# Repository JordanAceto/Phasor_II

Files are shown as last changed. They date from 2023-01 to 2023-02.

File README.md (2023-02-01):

# Phasor II Guitar Pedal

## 6-stage optical phase shifter pedal ala the Mu-tron II with extra features

- Fits in a Hammond BB style box
- Classic `RATE`, `DEPTH`, and `FEEDBACK` controls
- Powered by a standard guitar pedal style center-negative 9VDC power supply
- Expression pedal/CV input jack
    - Connect a Moog EP-3 or similar expression pedal with a TRS cable
    - Or inject a Control Voltage in the range [0v, +5v] with a TS cable
    - An internal jumper selects the destination for the modulation
        - `LFO DEPTH`
        - `LFO RATE`
        - `MANUAL SWEEP`

## [SCHEMATIC](https://github.com/JordanAceto/Phasor_II/blob/main/main_pcb/docs/phasor_II-schematic.pdf)

---

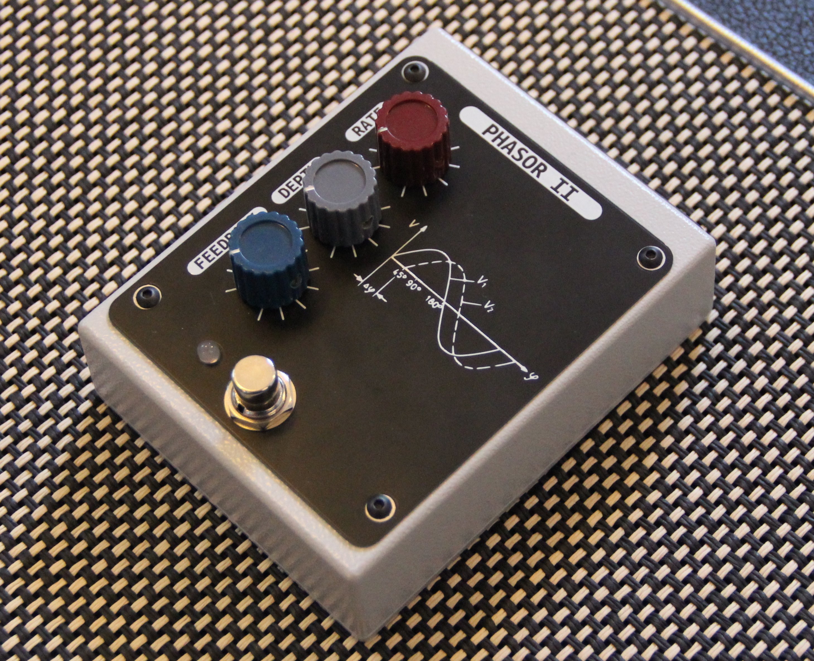
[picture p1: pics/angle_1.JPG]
front angle


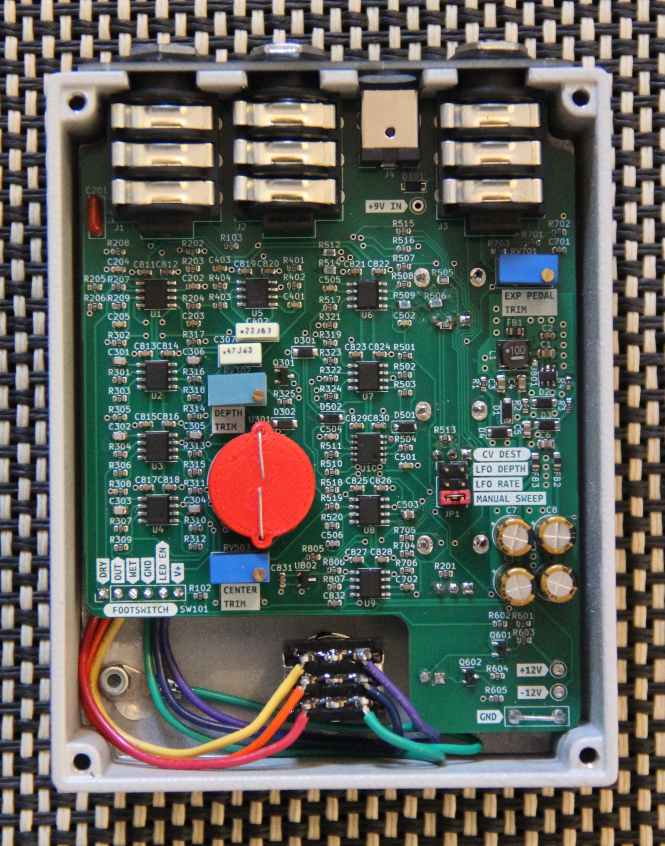
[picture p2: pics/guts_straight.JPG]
guts


---

## Calibration
### There are three points of calibration via internal trimpots
- `EXP PEDAL TRIM`
    - Connect a Moog EP-3 or similar expression pedal to the `CV-PED` jack and power the pedal ON
    - Make sure that any built in attenuators on the expression pedal are turned all the way up
    - With a multimeter set to DC volts measure the TIP of the `CV-PED` jack relative to ground (there is a convenient place to clip the black lead of the multimeter on the pcb)
    - Sweep the expression pedal all the way forwards, and adjust the `EXP PEDAL TRIM` trimpot until you measure +5VDC
    - Sweep the expression pedal back and forth and observe that the tip of the `CV-PED` jack sweeps from 0v to +5v
    
- `DEPTH TRIM`
    - This sets the width of the phasor sweep
    - Adjust by ear so that the sweep width is pleasant

- `CENTER TRIM`
    - This sets the center of the phasor sweep
    - Adjust by ear so that the bottom "turn around" feels good

- The depth and center trims are somewhat interactive, and should be trimmed together iteratively. Try a variety of rate and depth settings while calibrating.

- Note that while there is a light shield covering the photocells, ambient light will slightly change the sweep when the back panel is off
    - Perform calibration in a dim room. It doesn't need to be pitch black, just avoid shining bright lights right onto the guts

### There are no wrong or harmful settings, adjust these to taste. If the expression pedal feels better to you with a different voltage across it, go nuts.

---

## Current consumed from the 9VDC power input
### 9VDC    :   200mA

---

## Status of the project:

Task | Status |
---------|--------------|
Schematic capture | &#9745;
PCB layout | &#9745;
Test build | &#9745;
Safe to order boards| &#9745;

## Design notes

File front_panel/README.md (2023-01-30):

# Cheap and cheerful PCB panel option

## Important: Use a 0.8mm pcb

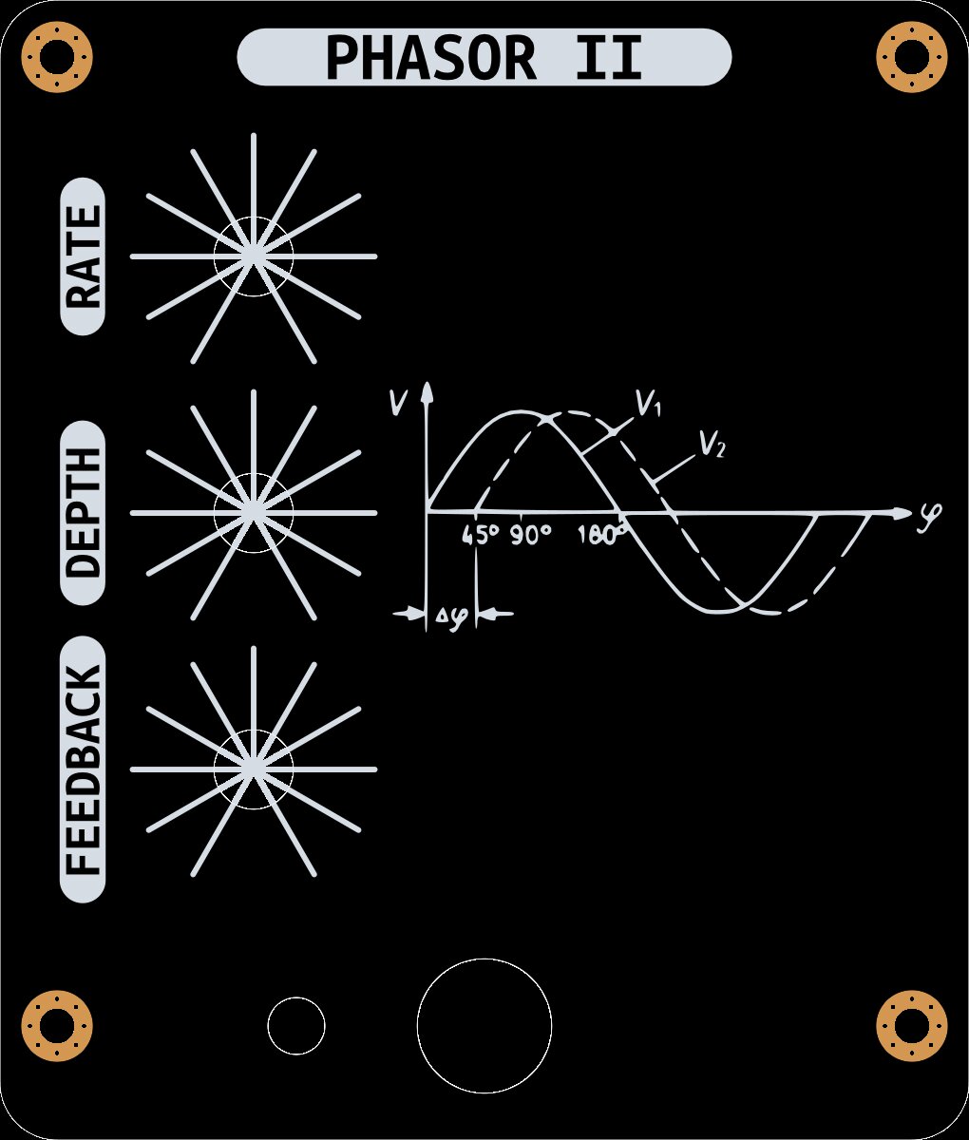
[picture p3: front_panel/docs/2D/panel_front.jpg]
Jack panel


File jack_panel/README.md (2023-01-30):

# Cheap and cheerful PCB panel option

## Important: Use a 1.6mm pcb
 
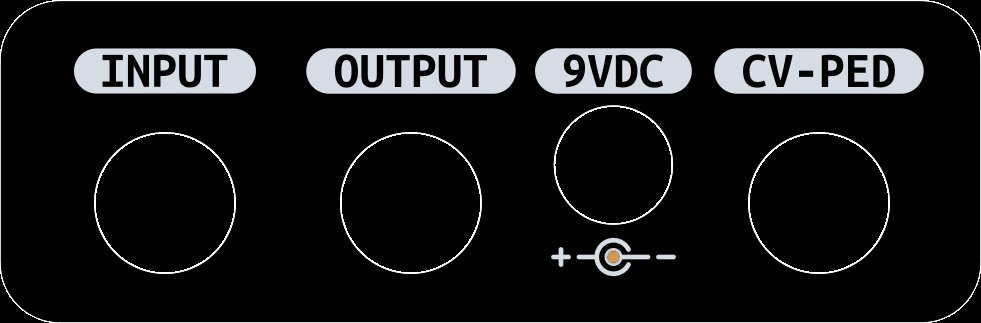
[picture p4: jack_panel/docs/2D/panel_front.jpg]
Jack panel


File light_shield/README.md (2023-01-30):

# 3D printed light shield

- Blocks ambient light from shining on the Light Dependent Resistor ring
- Attaches to the main PCB by soldering wire scraps through the holes and bending them over
- Available as a FreeCAD project and `.stl` file

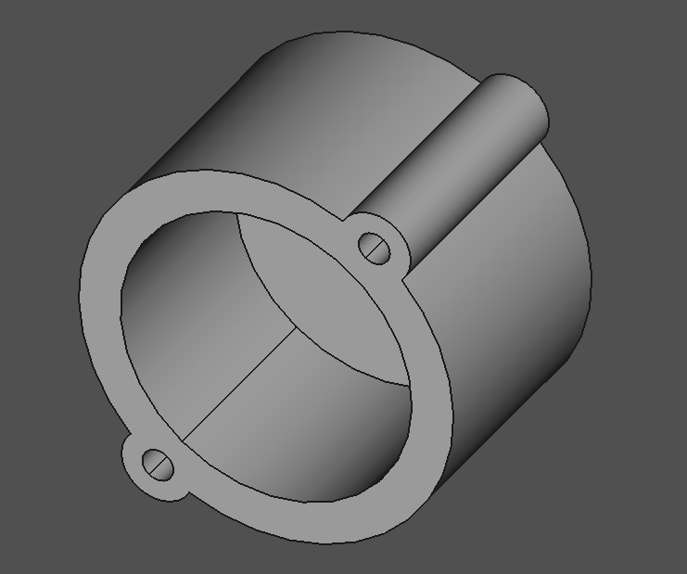
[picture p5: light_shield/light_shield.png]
Light shield


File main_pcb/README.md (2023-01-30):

# Main PCB

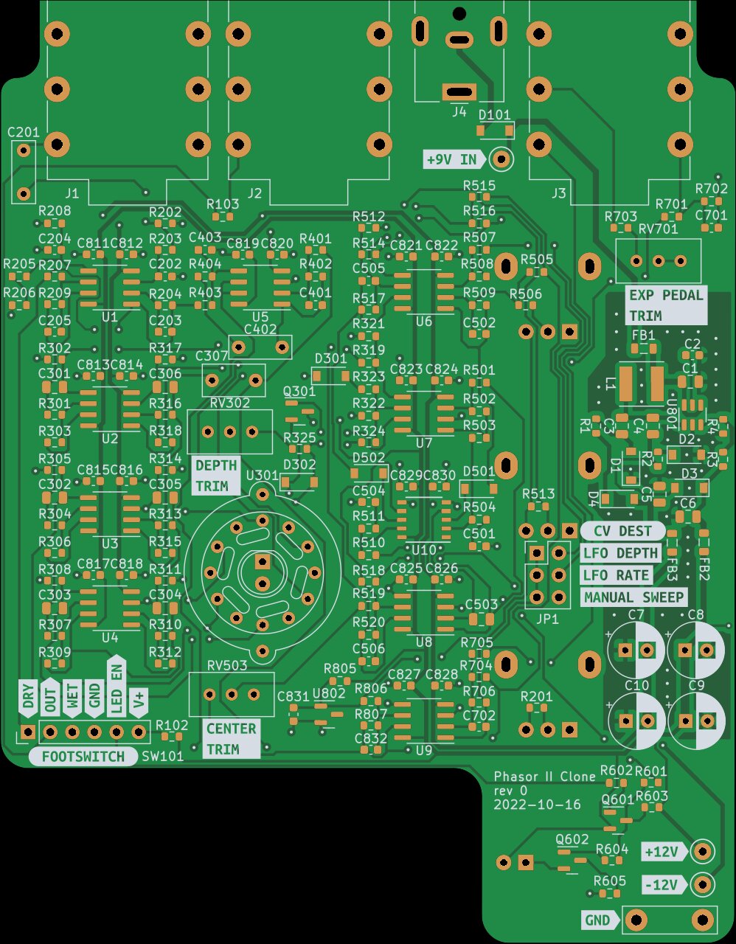
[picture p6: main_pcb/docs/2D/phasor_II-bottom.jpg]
PCB front


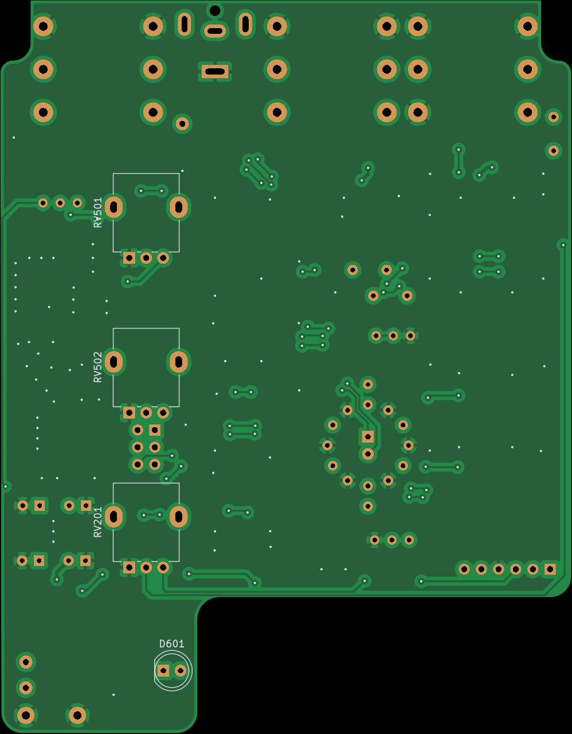
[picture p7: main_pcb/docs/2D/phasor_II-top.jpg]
PCB rear


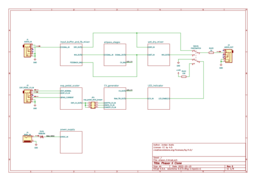
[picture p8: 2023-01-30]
main_pcb/docs/html_nav/images/cat_Schematic_phasor_II-schematic.png

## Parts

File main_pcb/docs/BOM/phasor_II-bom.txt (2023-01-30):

Row	Description	Part	References	Value	Footprint	Quantity Per PCB	Status	Datasheet
1	Unpolarized capacitor	C	C202	22p	C_0603_1608Metric	1	 	~
2	Unpolarized capacitor	C	C506	100p	C_0603_1608Metric	1	 	~
3	Unpolarized capacitor	C	C403	470p	C_0603_1608Metric	1	 	~
4	Unpolarized capacitor	C	C205 C401 C501 C502 C504 C505	1n	C_0603_1608Metric	6	 	~
5	Unpolarized capacitor	C	C204	3n3	C_0603_1608Metric	1	 	~
6	Unpolarized capacitor	C	C301 C302 C303 C304 C305 C306	6n8	C_0805_2012Metric	6	 	~
7	Unpolarized capacitor	C	C201	47n	C_Rect_L7.0mm_W2.5mm_P5.00mm	1	 	~
8	Unpolarized capacitor	C	C503	47n	C_0805_2012Metric	1	 	~
9	Unpolarized capacitor	C	C2 C203 C701 C702 C811 C812 C813 C814 C815 C816 C817 C818 C819 C820 C821 C822 C823 C824 C825 C826 C827 C828 C829 C830 C831 C832	100n	C_0603_1608Metric	26	 	~
10	Unpolarized capacitor	C	C402	220n	C_Rect_L7.0mm_W2.5mm_P5.00mm	1	 	~
11	Unpolarized capacitor	C	C307	470n	C_Rect_L7.0mm_W3.5mm_P5.00mm	1	 	~
12	Unpolarized capacitor	C	C3 C4	1u	C_0805_2012Metric	2	 	~
13	Unpolarized capacitor	C	C1 C5 C6	4u7	C_0805_2012Metric	3	 	~
14	Polarized capacitor	C_Polarized	C7 C8 C9 C10	10u	CP_Radial_D6.3mm_P2.50mm	4	 	~
15	75V 0.15A Fast Switching Diode, SOD-123	1N4148W	D301 D302	1N4148W	D_SOD-123	2	 	https://www.vishay.com/docs/85748/1n4148w.pdf
16	Schottky diode	D_Schottky	D1 D2 D3 D4 D101	B5819W	D_SOD-123	5	 	~
17	Schottky diode	D_Schottky	D501 D502	BAT48ZFILM	D_SOD-123	2	 	~
18	Light emitting diode	LED	D601	LED	LED_D5.0mm	1	 	~
19	Ferrite bead, small symbol	FerriteBead_Small	FB1 FB2 FB3	100R @ 100MHz	L_0805_2012Metric	3	 	~
20	DC Barrel Jack	Jack-DC	J4	9VDC_IN	BarrelJack_CUI_PJ-063AH_Horizontal	1	 	~
21	Audio Jack, 3 Poles (Stereo / TRS), Switched Poles (Normalling)	AudioJack3_Switch	J1 J2 J3	AUDIO_IN	Jack_6.35mm_Neutrik_NMJ6HCD2_Horizontal	3	 	~
22	Generic connector, double row, 02x03, odd/even pin numbering scheme (row 1 odd numbers, row 2 even numbers), script generated (kicad-library-utils/schlib/autogen/connector/)	Conn_02x03_Odd_Even	JP1	exp_pedal_dest_jumper	PinHeader_2x03_P2.54mm_Vertical	1	 	~
23	Inductor symbol for simulation only	INDUCTOR	L1	10uH, 1.2A	L_Taiyo-Yuden_NR-50xx	1	 	~
24	0.2A Ic, 40V Vce, Small Signal NPN Transistor, SOT-23	MMBT3904	Q301	MMBT3904	SOT-23	1	 	https://www.onsemi.com/pub/Collateral/2N3903-D.PDF
25	-0.2A Ic, -40V Vce, Small Signal PNP Transistor, SOT-23	MMBT3906	Q601 Q602	MMBT3906	SOT-23	2	 	https://www.onsemi.com/pub/Collateral/2N3906-D.PDF
26	Resistor	R	R1 R2	1	R_0603_1608Metric	2	 	~
27	Resistor	R	R325	220	R_0603_1608Metric	1	 	~
28	Resistor	R	R504 R511 R605	270	R_0603_1608Metric	3	 	~
29	Resistor	R	R103	1k	R_0603_1608Metric	1	 	~
30	Resistor	R	R206	1k5	R_0603_1608Metric	1	 	~
31	Resistor	R	R805	1k8	R_0603_1608Metric	1	 	~
32	Resistor	R	R203 R321	3k9	R_0603_1608Metric	2	 	~
33	Resistor	R	R201 R205 R207 R208 R209 R301 R303 R304 R306 R307 R309 R310 R312 R313 R315 R316 R318 R401 R402 R404	4k7	R_0603_1608Metric	20	 	~
34	Resistor	R	R102 R323 R513 R701 R702	10k	R_0603_1608Metric	5	 	~
35	Resistor	R	R403 R508	12k	R_0603_1608Metric	2	 	~
36	Resistor	R	R4	13k3	R_0603_1608Metric	1	 	~
37	Resistor	R	R516	18k	R_0603_1608Metric	1	 	~
38	Resistor	R	R703	20k	R_0603_1608Metric	1	 	~
39	Resistor	R	R503 R603	22k	R_0603_1608Metric	2	 	~
40	Resistor	R	R509	30k	R_0603_1608Metric	1	 	~
41	Resistor	R	R601	33k	R_0603_1608Metric	1	 	~
42	Resistor	R	R519	39k	R_0603_1608Metric	1	 	~
43	Resistor	R	R505 R517	56k	R_0603_1608Metric	2	 	~
44	Resistor	R	R319 R322	68k	R_0603_1608Metric	2	 	~
45	Resistor	R	R501 R507 R510 R515 R518 R520 R602 R604 R705 R806 R807	100k	R_0603_1608Metric	11	 	~
46	Resistor	R	R506	110k	R_0603_1608Metric	1	 	~
47	Resistor	R	R3	114k	R_0603_1608Metric	1	 	~
48	Resistor	R	R512 R514	120k	R_0603_1608Metric	2	 	~
49	Resistor	R	R704 R706	200k	R_0603_1608Metric	2	 	~
50	Resistor	R	R302 R305 R308 R311 R314 R317 R324 R502	220k	R_0603_1608Metric	8	 	~
51	Resistor	R	R202 R204	390k	R_0603_1608Metric	2	 	~
52	Trim-potentiometer	R_Potentiometer_Trim	RV302	1k	Potentiometer_Bourns_3296W_Vertical	1	 	~
53	Potentiometer	R_Potentiometer	RV201	10k	Potentiometer_Alpha_RD901F-40-00D_Single_Vertical	1	 	~
54	Potentiometer	R_Potentiometer	RV501 RV502	100k	Potentiometer_Alpha_RD901F-40-00D_Single_Vertical	2	 	~
55	Trim-potentiometer	R_Potentiometer_Trim	RV503 RV701	100k	Potentiometer_Bourns_3296W_Vertical	2	 	~
56	Momentary Switch, dual pole double throw	SW_Push_DPDT	SW101	FOOTSWITCH	PinHeader_1x06_P2.54mm_Vertical	1	 	~
57		LDR_ring	U301	LDR_ring	LDR_ring	1	 	
58	5.000V Precision Micropower Shunt Voltage Reference, SOT-23	LM4040DBZ-5	U802	LM4040DBZ-5	SOT-23	1	 	http://www.ti.com/lit/ds/symlink/lm4040-n.pdf
59		LT3467A	U801	LT3467A	TSOT-23-6	1	 	
60	Dual General Purpose, Operational Amplifier, DIP-8/SOIC-8/SSOP-8	RC4558	U1 U2 U3 U4 U5	RC4558	SOIC-8_3.9x4.9mm_P1.27mm	5	 	http://www.ti.com/lit/ds/symlink/rc4558.pdf
61		SSI2162	U10	SSI2162	SSOP-10_3.9x4.9mm_P1.00mm	1	 	https://www.soundsemiconductor.com/downloads/ssi2162datasheet.pdf
62	Dual Low-Noise JFET-Input Operational Amplifiers, DIP-8/SOIC-8	TL072	U6 U7 U8 U9	TL072	SOIC-8_3.9x4.9mm_P1.27mm	4	 	http://www.ti.com/lit/ds/symlink/tl071.pdf

Project info:
Schematic:	phasor_II
Variant:	default
Revision:	0
Date:	2022-10-15
KiCad Version:	6.0.5+dfsg-1~bpo11+1
Statistics:
Component Groups:	62
Component Count:	174 (143 SMD/ 20 THT)
Fitted Components:	174 (143 SMD/ 20 THT)
Number of PCBs:	1
Total Components:	174

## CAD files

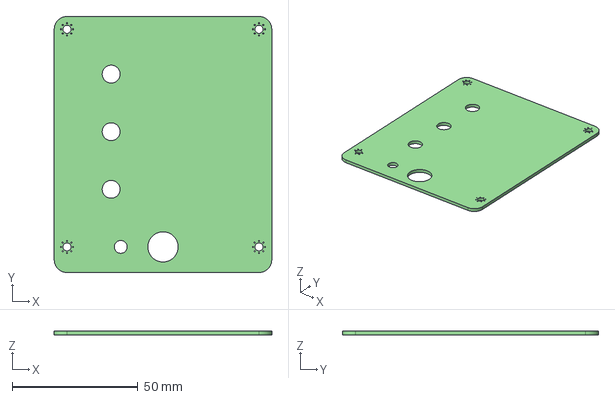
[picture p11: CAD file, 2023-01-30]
front_panel/docs/CAD/phasor_II_front_panel-3D.step
86.4 x 101.6 x 1.60 mm

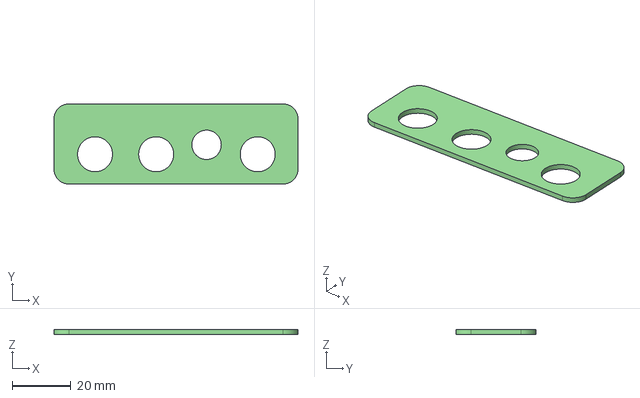
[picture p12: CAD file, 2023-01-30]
jack_panel/docs/CAD/phasor_II_jack_panel-3D.step
83.1 x 27.3 x 1.60 mm

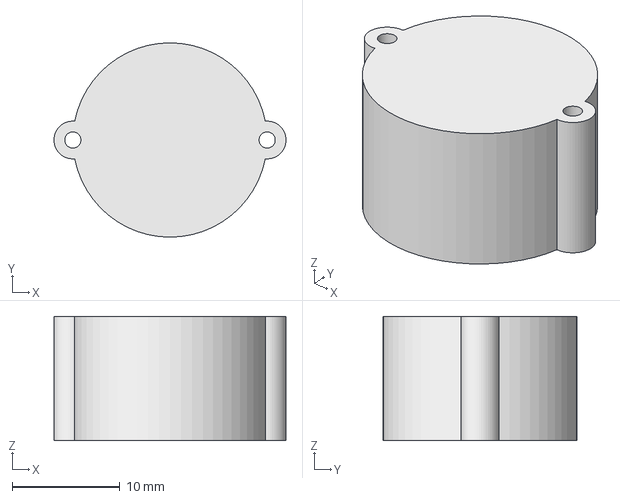
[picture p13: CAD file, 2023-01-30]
light_shield/light_shield.FCStd
21.5 x 18.0 x 11.5 mm

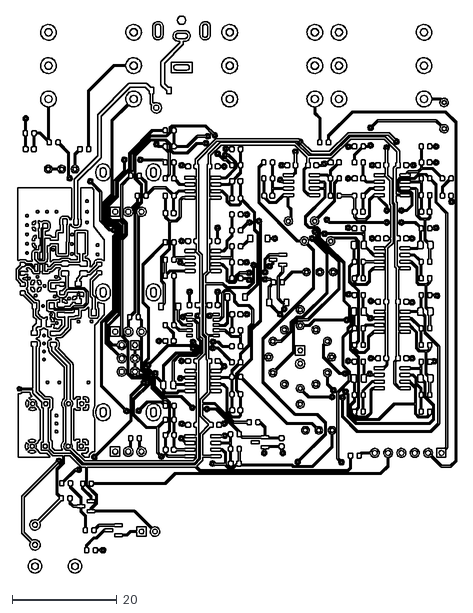
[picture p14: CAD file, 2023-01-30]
main_pcb/docs/CAD/phasor_II-B_Cu.dxf
84.0 x 106.2

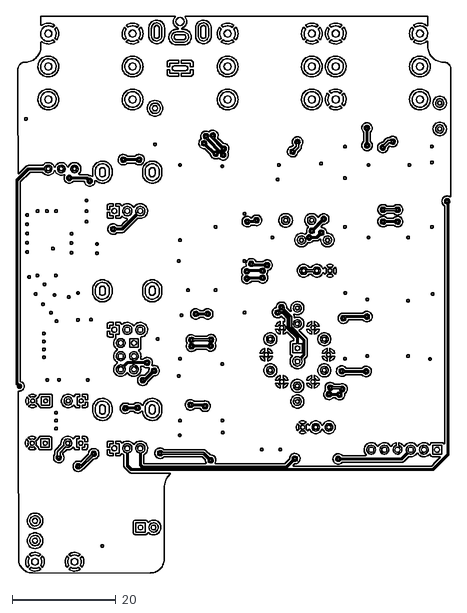
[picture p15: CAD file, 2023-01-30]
main_pcb/docs/CAD/phasor_II-F_Cu.dxf
83.8 x 107.3

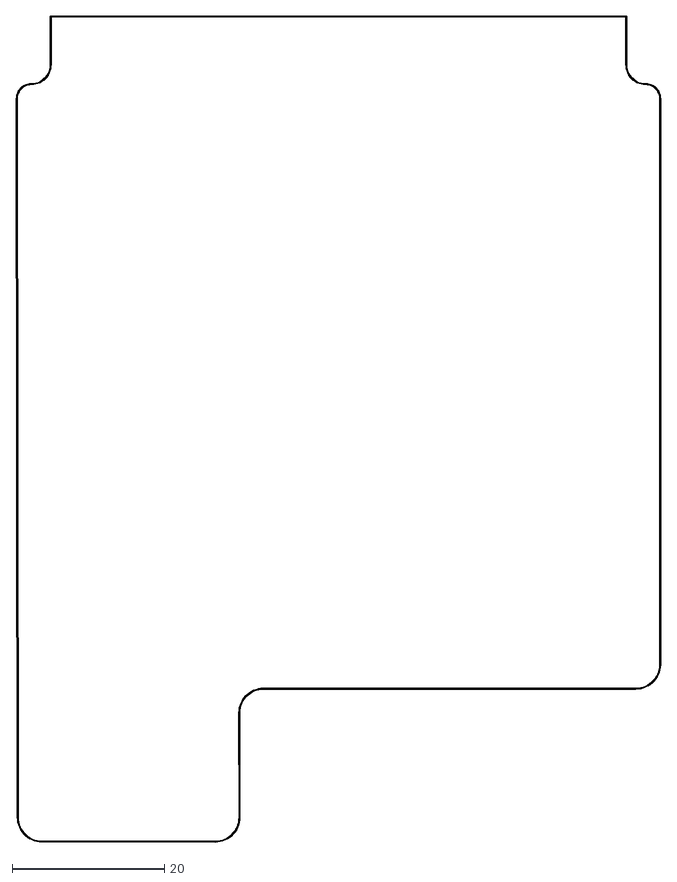
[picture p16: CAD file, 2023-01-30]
main_pcb/docs/CAD/phasor_II-Edge_Cuts.dxf
84.6 x 108.4

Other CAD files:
light_shield/light_shield.stl
main_pcb/docs/CAD/phasor_II-B_Mask.dxf
main_pcb/docs/CAD/phasor_II-B_Silkscreen.dxf
main_pcb/docs/CAD/phasor_II-F_Mask.dxf
main_pcb/docs/CAD/phasor_II-F_Silkscreen.dxf

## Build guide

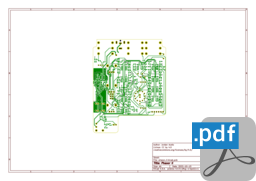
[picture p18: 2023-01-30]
main_pcb/docs/html_nav/images/cat_pdf_pcb_print_BCu_phasor_II-B_Cu.png

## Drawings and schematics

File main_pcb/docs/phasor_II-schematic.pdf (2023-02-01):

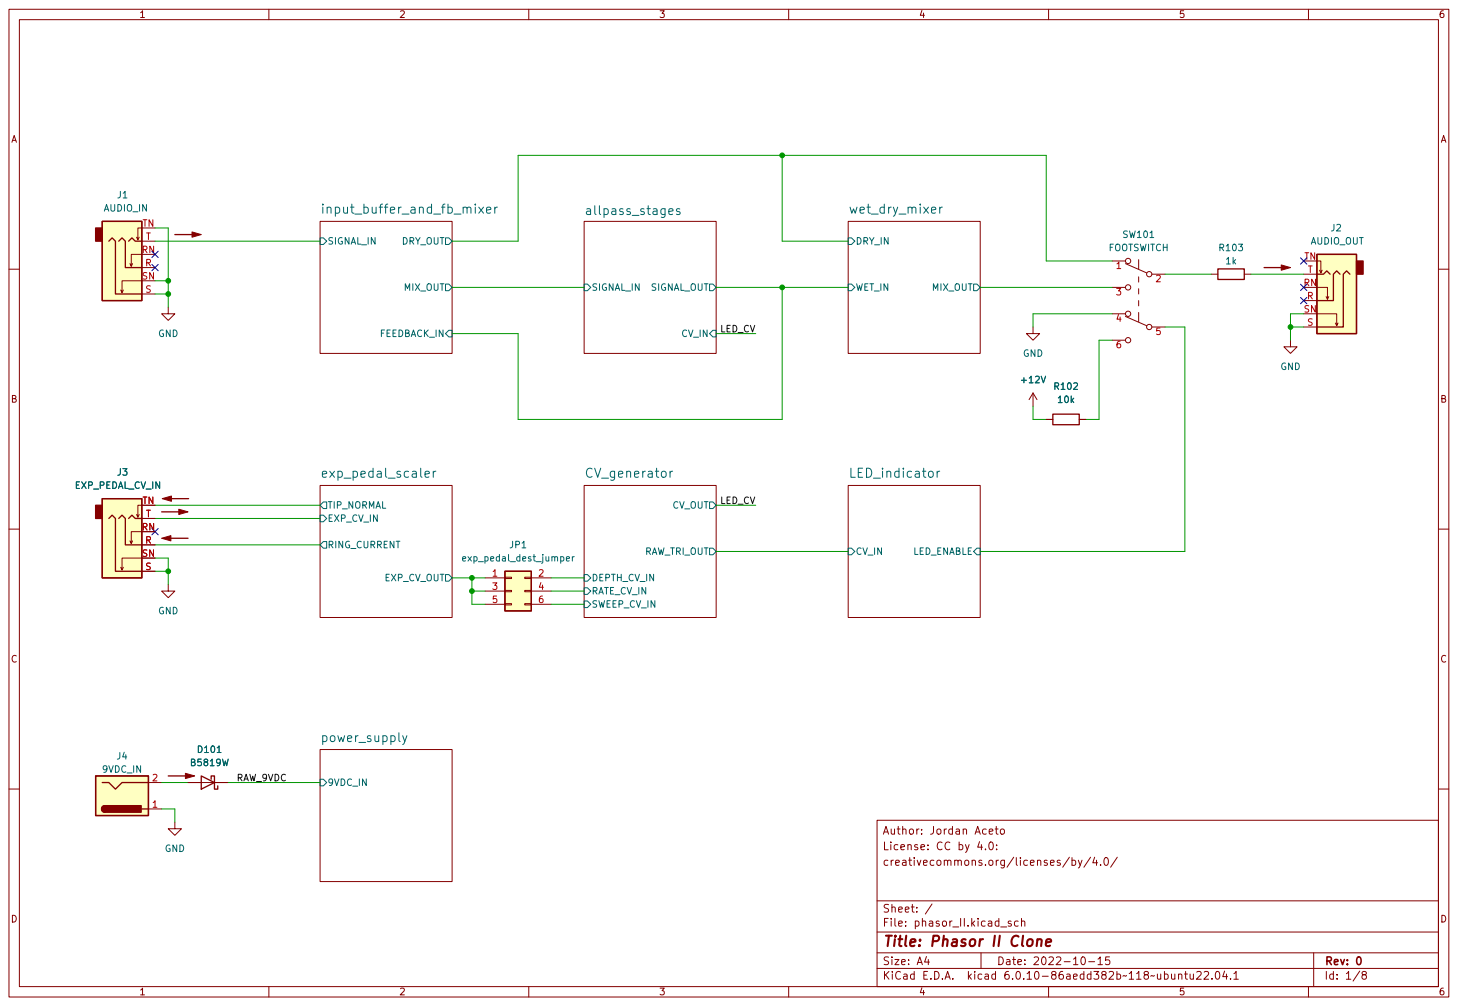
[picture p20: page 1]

File: phasor_II.kicad_sch Sheet: / creativecommons.org/licenses/by/4.0/

Id: 1/8 Title: Phasor II Clone

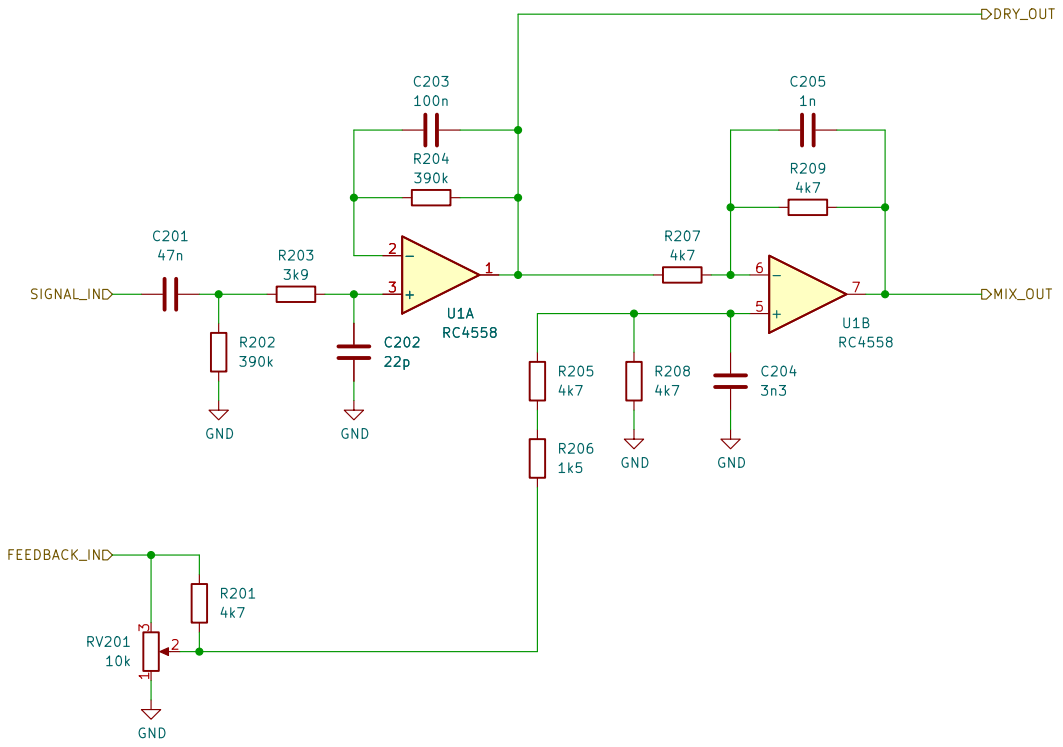
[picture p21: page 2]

License: CC by 4.0: Author: Jordan Aceto

creativecommons.org/licenses/by/4.0/

Sheet: /input_buffer_and_fb_mixer/
File: input_buffer_and_fb_mixer.kicad_sch
Id: 2/8 Title: Phasor II Clone

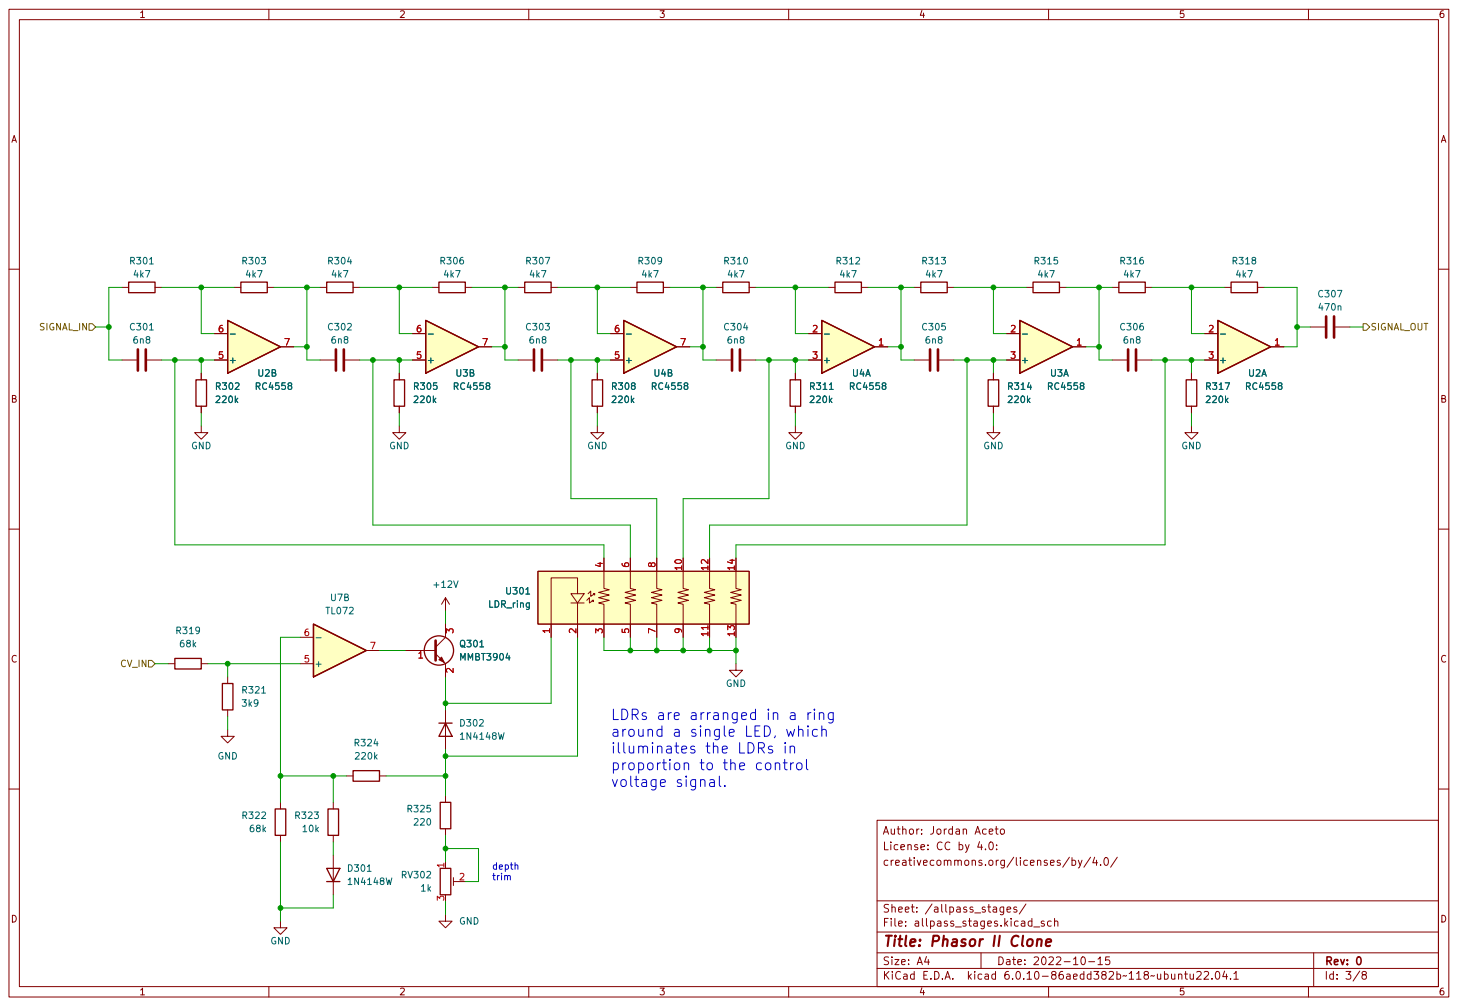
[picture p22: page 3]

around a single LED, which
illuminates the LDRs in
proportion to the control

License: CC by 4.0: Author: Jordan Aceto R325

creativecommons.org/licenses/by/4.0/

Sheet: /allpass_stages/
File: allpass_stages.kicad_sch
Id: 3/8 Title: Phasor II Clone

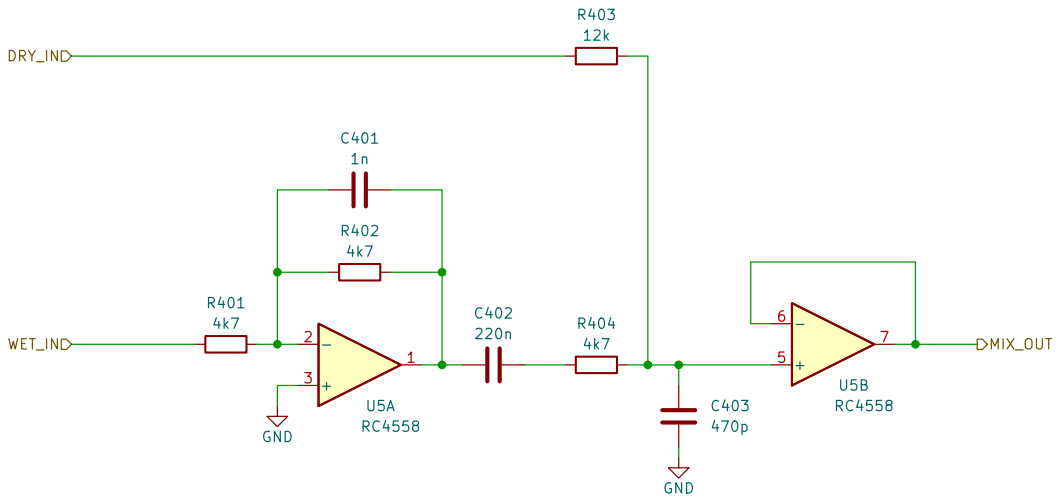
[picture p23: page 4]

License: CC by 4.0: Author: Jordan Aceto C401

creativecommons.org/licenses/by/4.0/

Sheet: /wet_dry_mixer/
File: wet_dry_mixer.kicad_sch
Id: 4/8 Title: Phasor II Clone

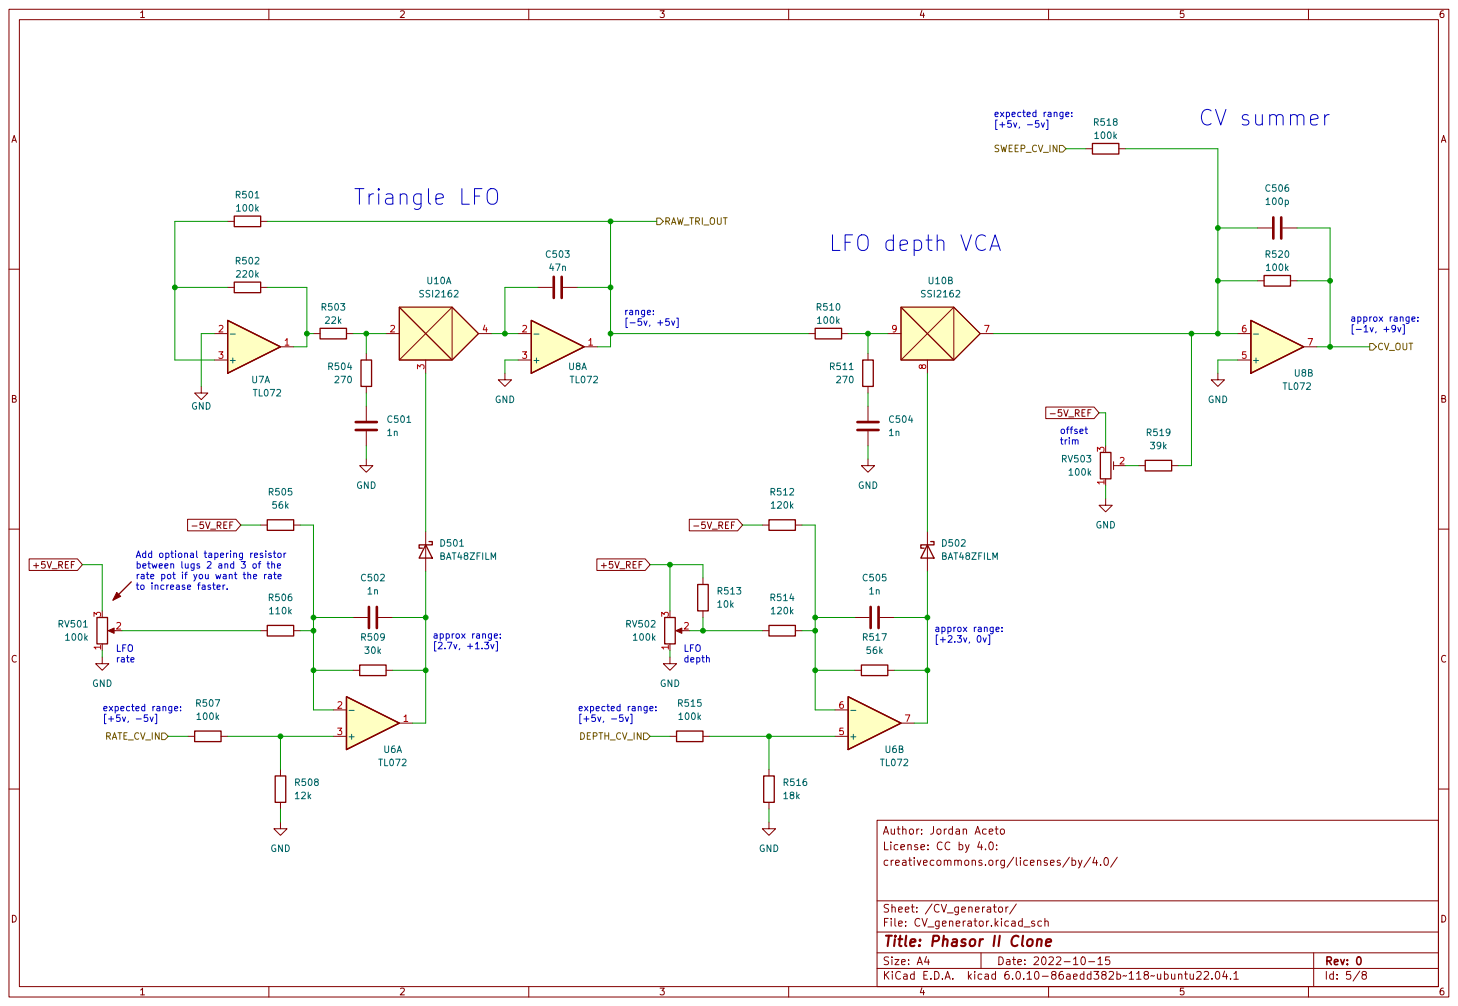
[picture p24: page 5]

License: CC by 4.0: Author: Jordan Aceto GND

Add optional tapering resistor
between lugs 2 and 3 of the
rate pot if you want the rate

creativecommons.org/licenses/by/4.0/

Sheet: /CV_generator/
File: CV_generator.kicad_sch
Id: 5/8 Title: Phasor II Clone

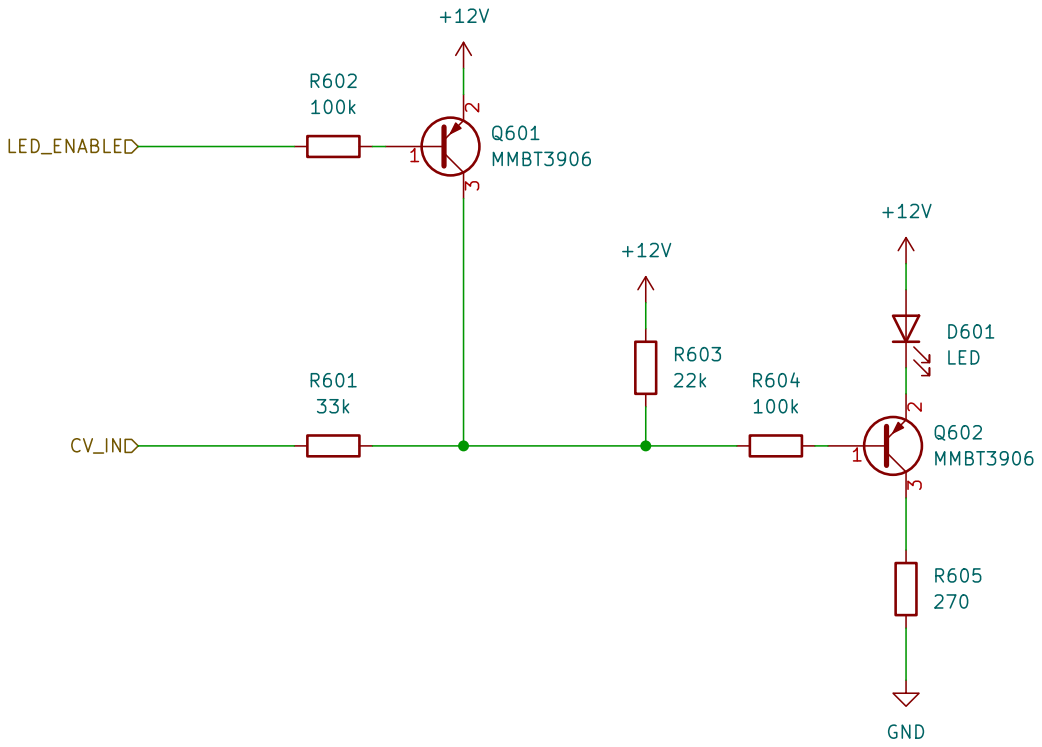
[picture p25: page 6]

License: CC by 4.0: Author: Jordan Aceto R605

creativecommons.org/licenses/by/4.0/

Sheet: /LED_indicator/
File: LED_indicator.kicad_sch
Id: 6/8 Title: Phasor II Clone

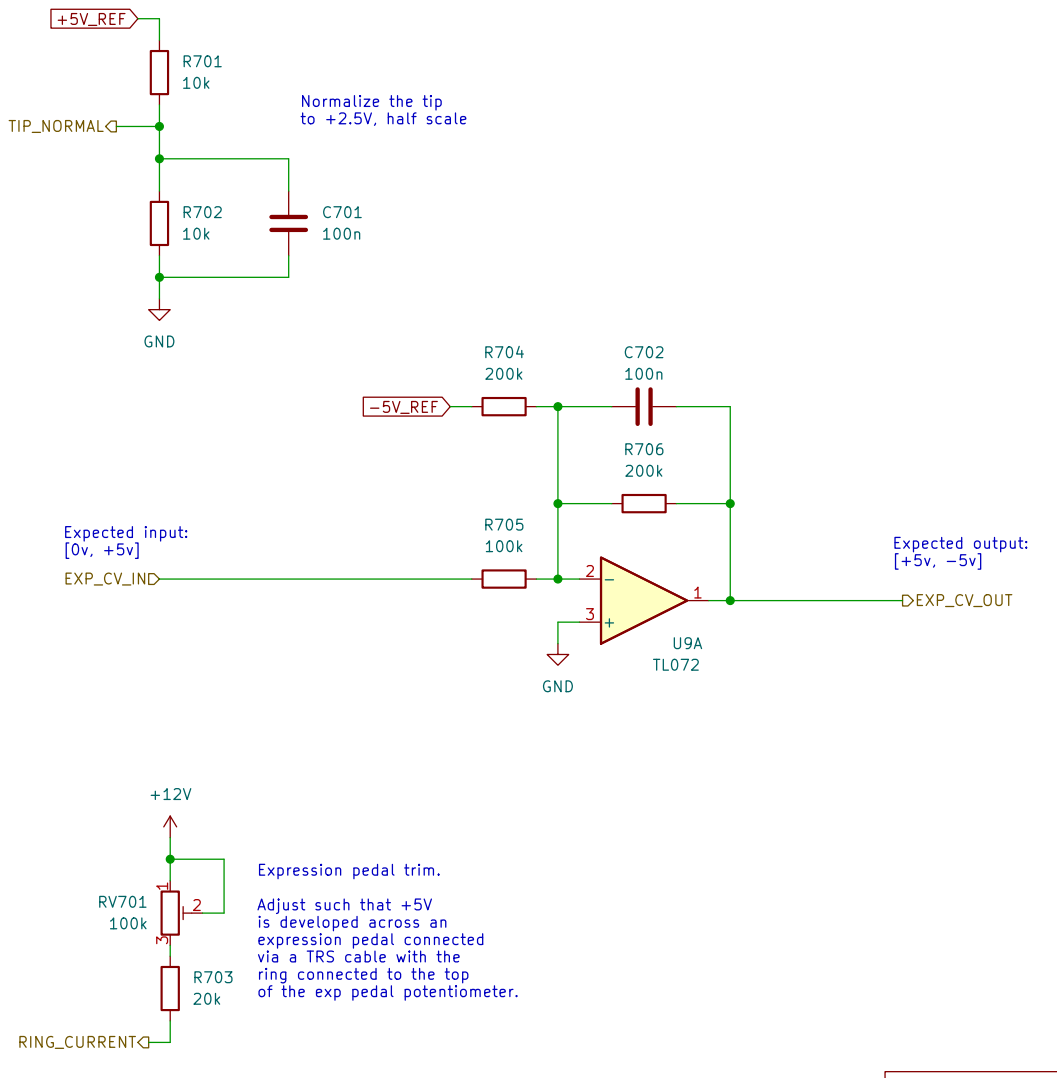
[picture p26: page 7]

to +2.5V, half scale Expected input:

License: CC by 4.0: Author: Jordan Aceto R705

Adjust such that +5V
is developed across an
expression pedal connected via a TRS cable with the

ring connected to the top
of the exp pedal potentiometer.

creativecommons.org/licenses/by/4.0/

Sheet: /exp_pedal_scaler/
File: exp_pedal_scaler.kicad_sch
Id: 7/8 Title: Phasor II Clone

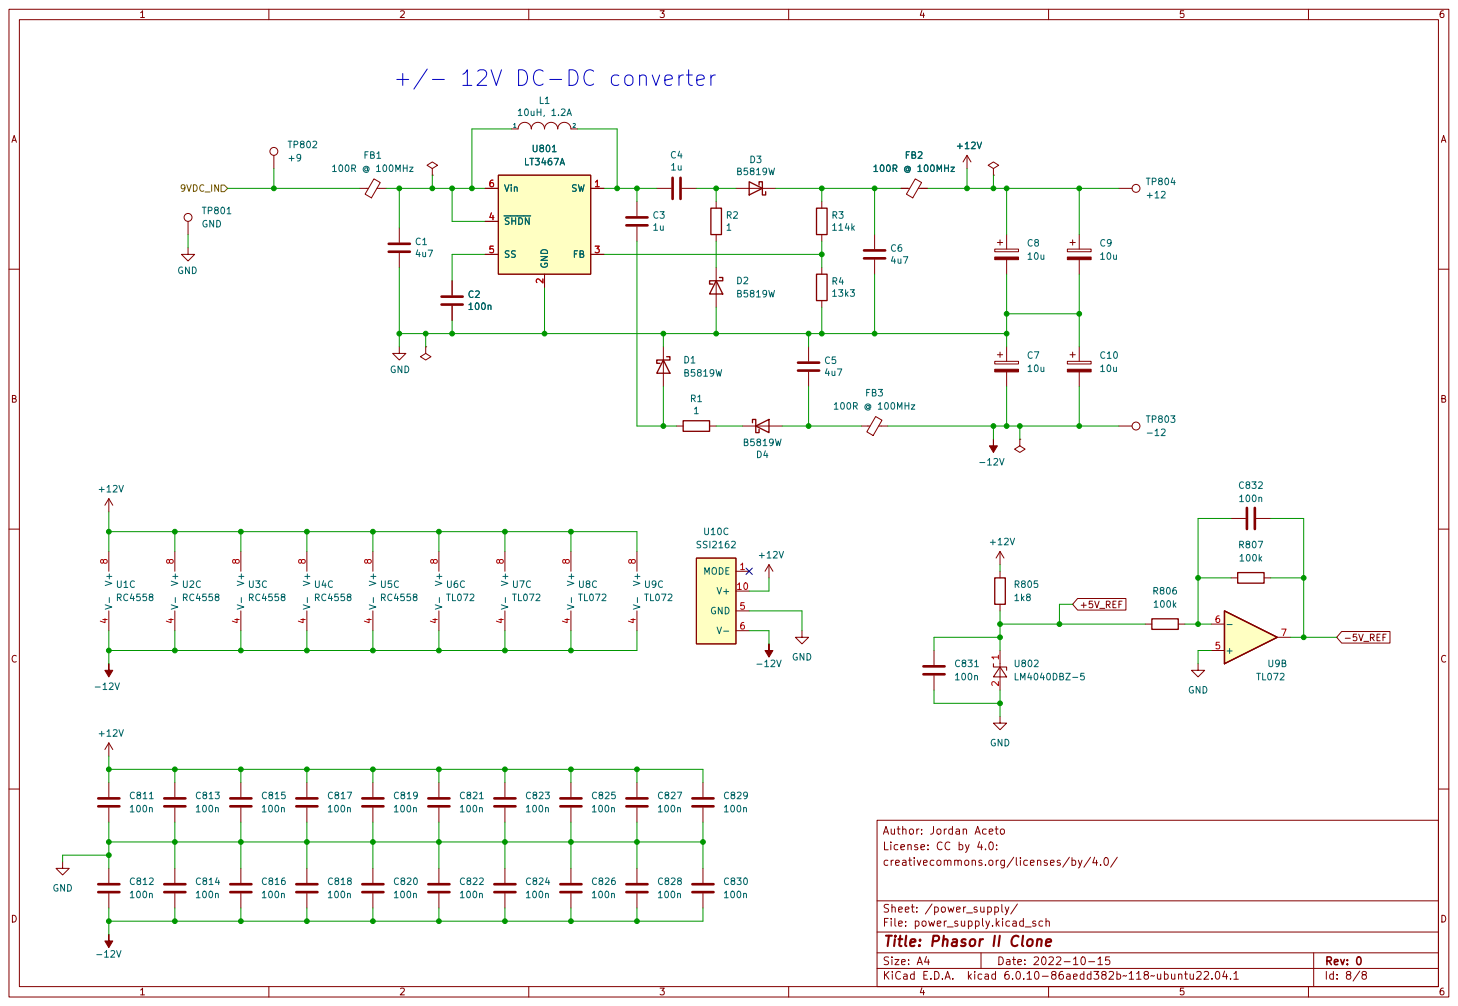
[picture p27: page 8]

2 FB 3 ~{SHDN} 4 SS 5 Vin 6 U801

2 FB 3 ~{SHDN} 4 SS 5 Vin 6 C2

License: CC by 4.0: Author: Jordan Aceto C830

creativecommons.org/licenses/by/4.0/

Sheet: /power_supply/
File: power_supply.kicad_sch
Id: 8/8 Title: Phasor II Clone

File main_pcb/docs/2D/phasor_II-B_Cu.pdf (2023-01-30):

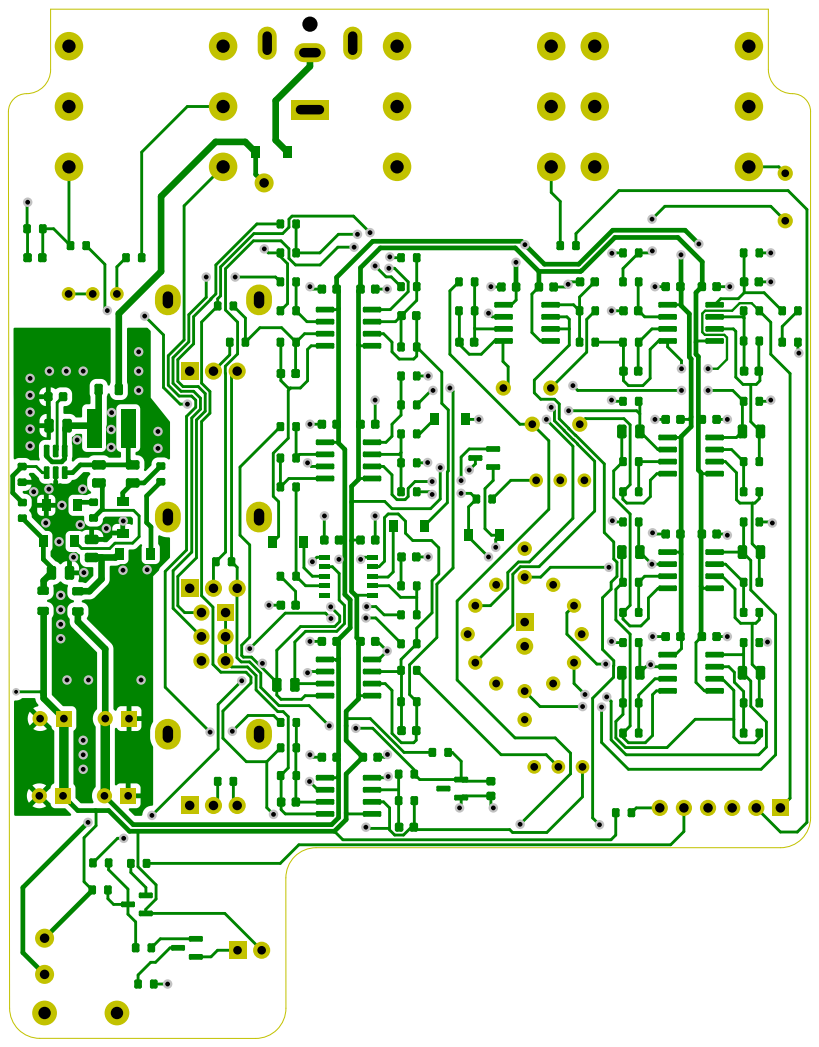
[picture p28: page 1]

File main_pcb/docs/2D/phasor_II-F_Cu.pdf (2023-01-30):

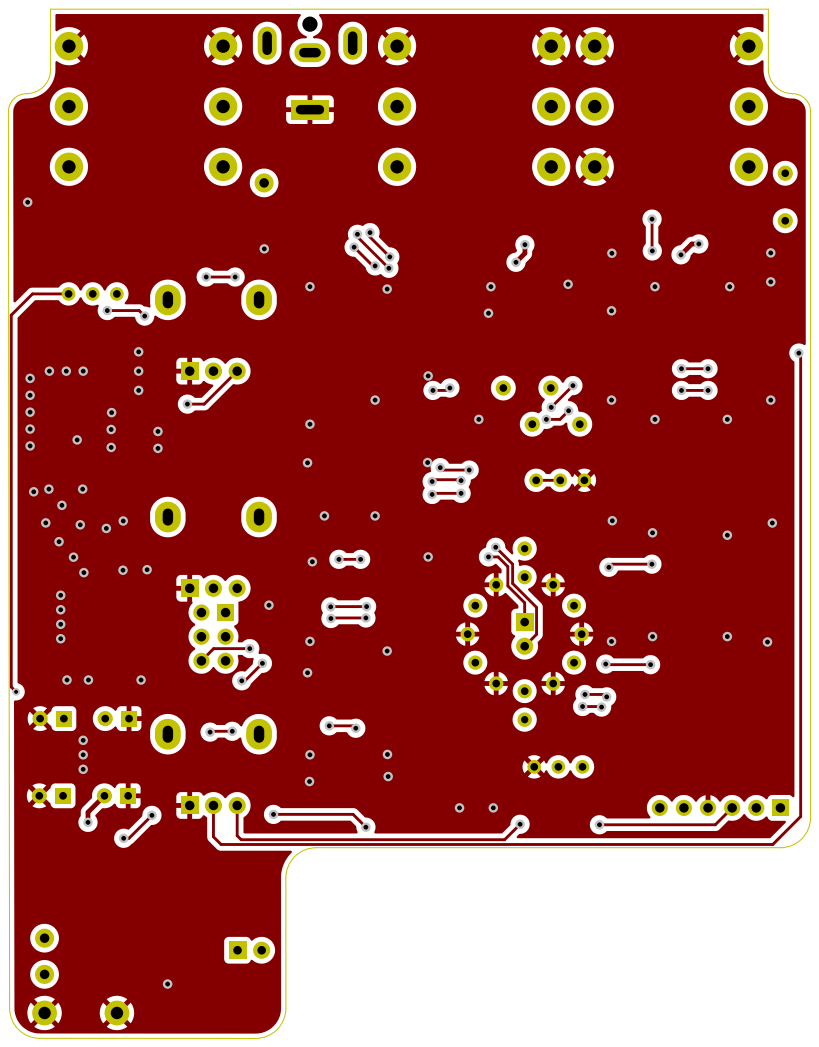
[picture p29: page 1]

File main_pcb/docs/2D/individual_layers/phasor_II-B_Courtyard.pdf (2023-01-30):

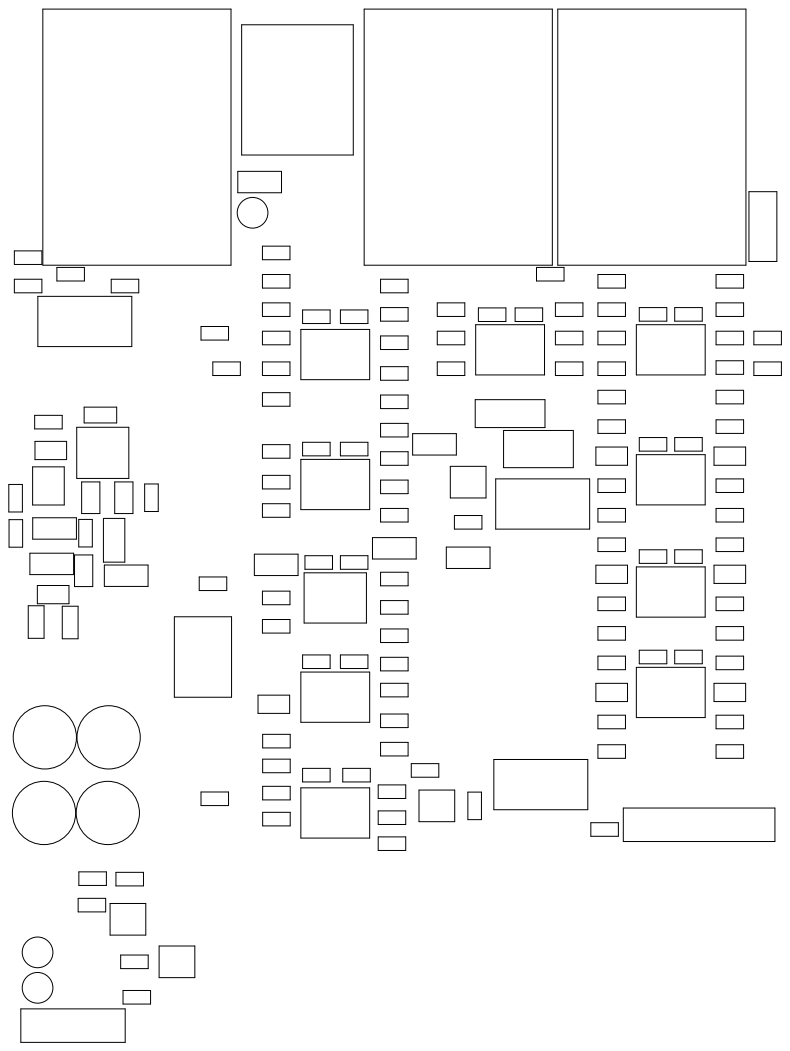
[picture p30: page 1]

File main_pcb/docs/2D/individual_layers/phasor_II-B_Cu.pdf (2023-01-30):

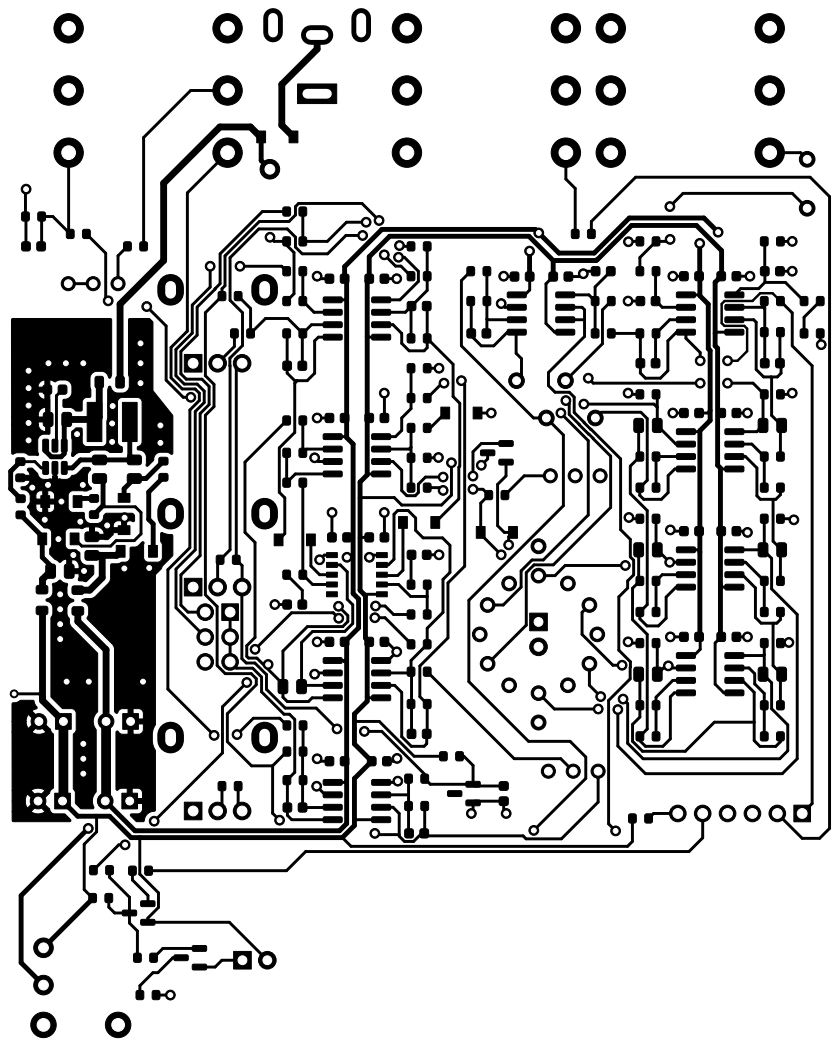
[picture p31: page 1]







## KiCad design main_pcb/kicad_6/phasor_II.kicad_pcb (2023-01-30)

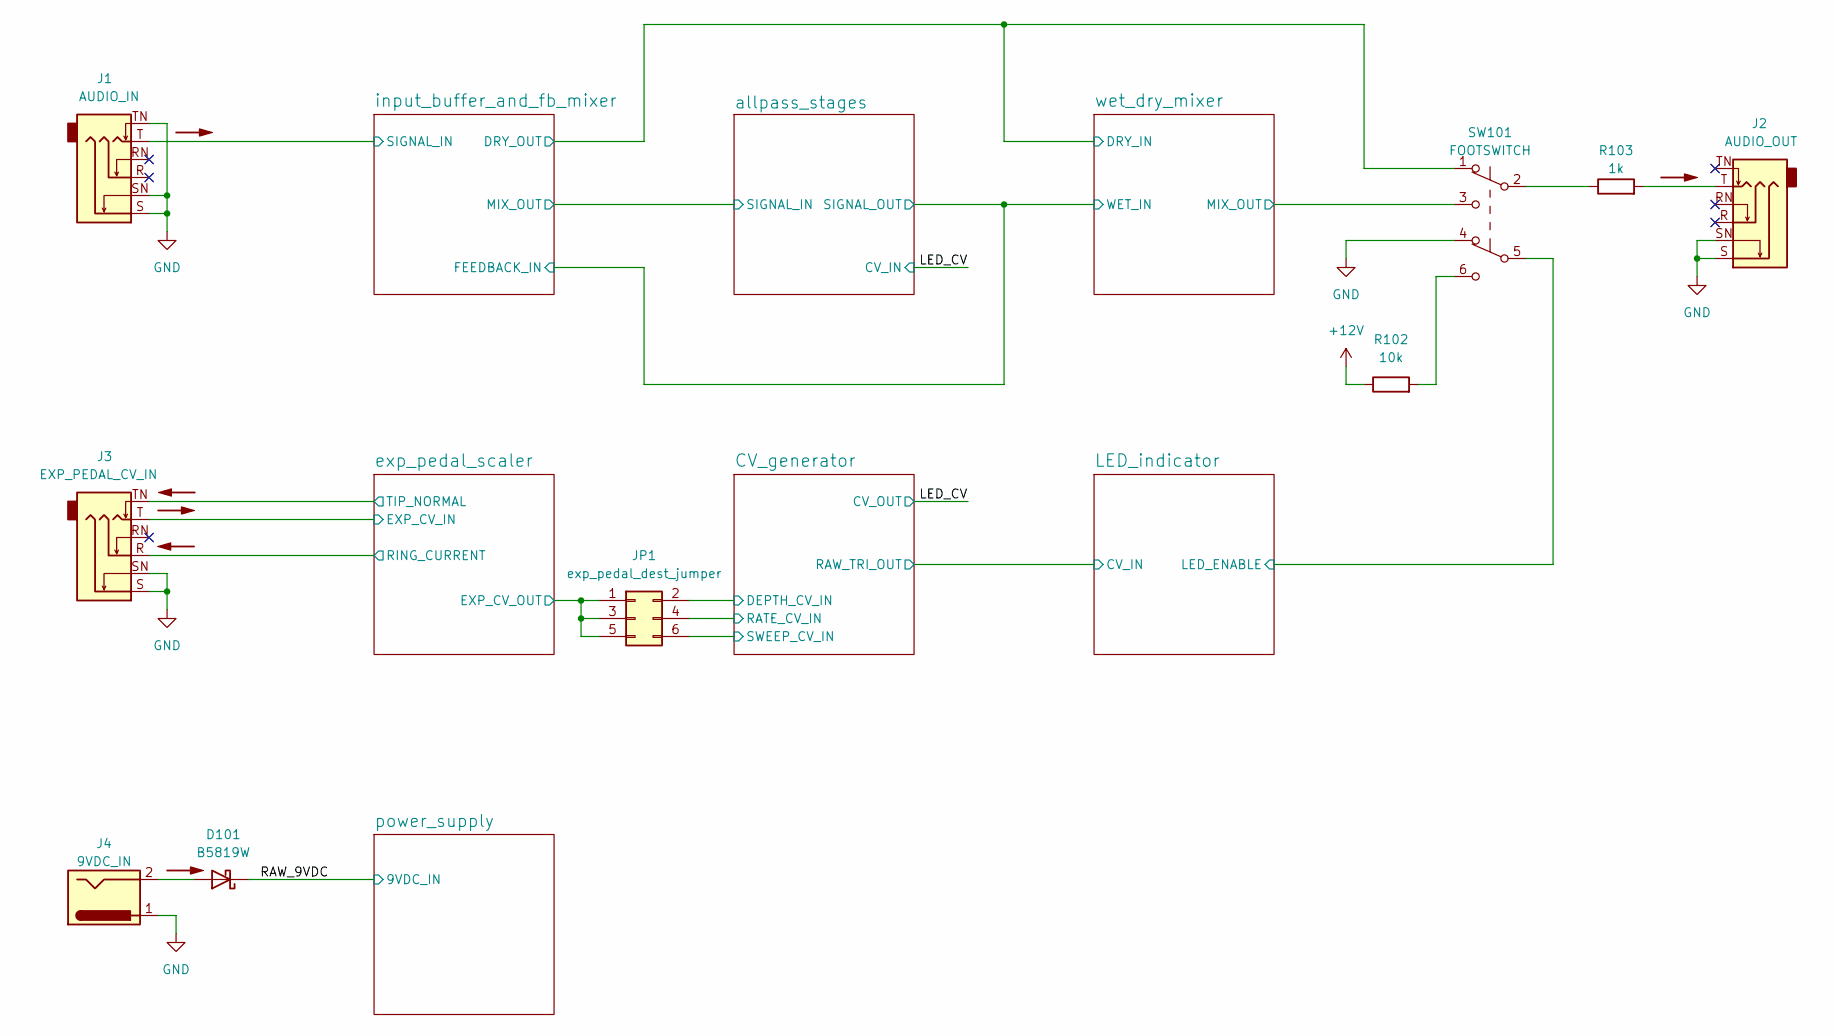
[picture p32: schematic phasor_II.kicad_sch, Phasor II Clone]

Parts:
D101: B5819W; D_SOD-123
J1: AUDIO_IN; Jack_6.35mm_Neutrik_NMJ6HCD2_Horizontal
J2: AUDIO_OUT; Jack_6.35mm_Neutrik_NMJ6HCD2_Horizontal
J3: EXP_PEDAL_CV_IN; Jack_6.35mm_Neutrik_NMJ6HCD2_Horizontal
J4: 9VDC_IN; BarrelJack_CUI_PJ-063AH_Horizontal
JP1: exp_pedal_dest_jumper; PinHeader_2x03_P2.54mm_Vertical
R102: 10k; R_0603_1608Metric
R103: 1k; R_0603_1608Metric
SW101: FOOTSWITCH; PinHeader_1x06_P2.54mm_Vertical

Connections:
+12V: R102.1; also elsewhere on the board
/CV_generator/DEPTH_CV_IN: JP1.2; also elsewhere on the board
/CV_generator/RATE_CV_IN: JP1.4; also elsewhere on the board
/CV_generator/SWEEP_CV_IN: JP1.6; also elsewhere on the board
/LED_indicator/LED_ENABLE: SW101.5 (B); also elsewhere on the board
/RAW_9VDC: D101.1 (K); also elsewhere on the board
/exp_pedal_scaler/EXP_CV_IN: J3.T; also elsewhere on the board
/exp_pedal_scaler/EXP_CV_OUT: JP1.1, JP1.3, JP1.5; also elsewhere on the board
/exp_pedal_scaler/RING_CURRENT: J3.R; also elsewhere on the board
/exp_pedal_scaler/TIP_NORMAL: J3.TN; also elsewhere on the board
/input_buffer_and_fb_mixer/DRY_OUT: SW101.1 (A); also elsewhere on the board
/input_buffer_and_fb_mixer/SIGNAL_IN: J1.T; also elsewhere on the board
/wet_dry_mixer/MIX_OUT: SW101.3 (C); also elsewhere on the board
GND: J1.S, J1.SN, J1.TN, J2.S, J2.SN, J3.S, J3.SN, J4.1, SW101.4 (A); also elsewhere on the board
unnamed: D101.2 (A), J4.2
unnamed: J2.T, R103.2
unnamed: R102.2, SW101.6 (C)
unnamed: R103.1, SW101.2 (B)

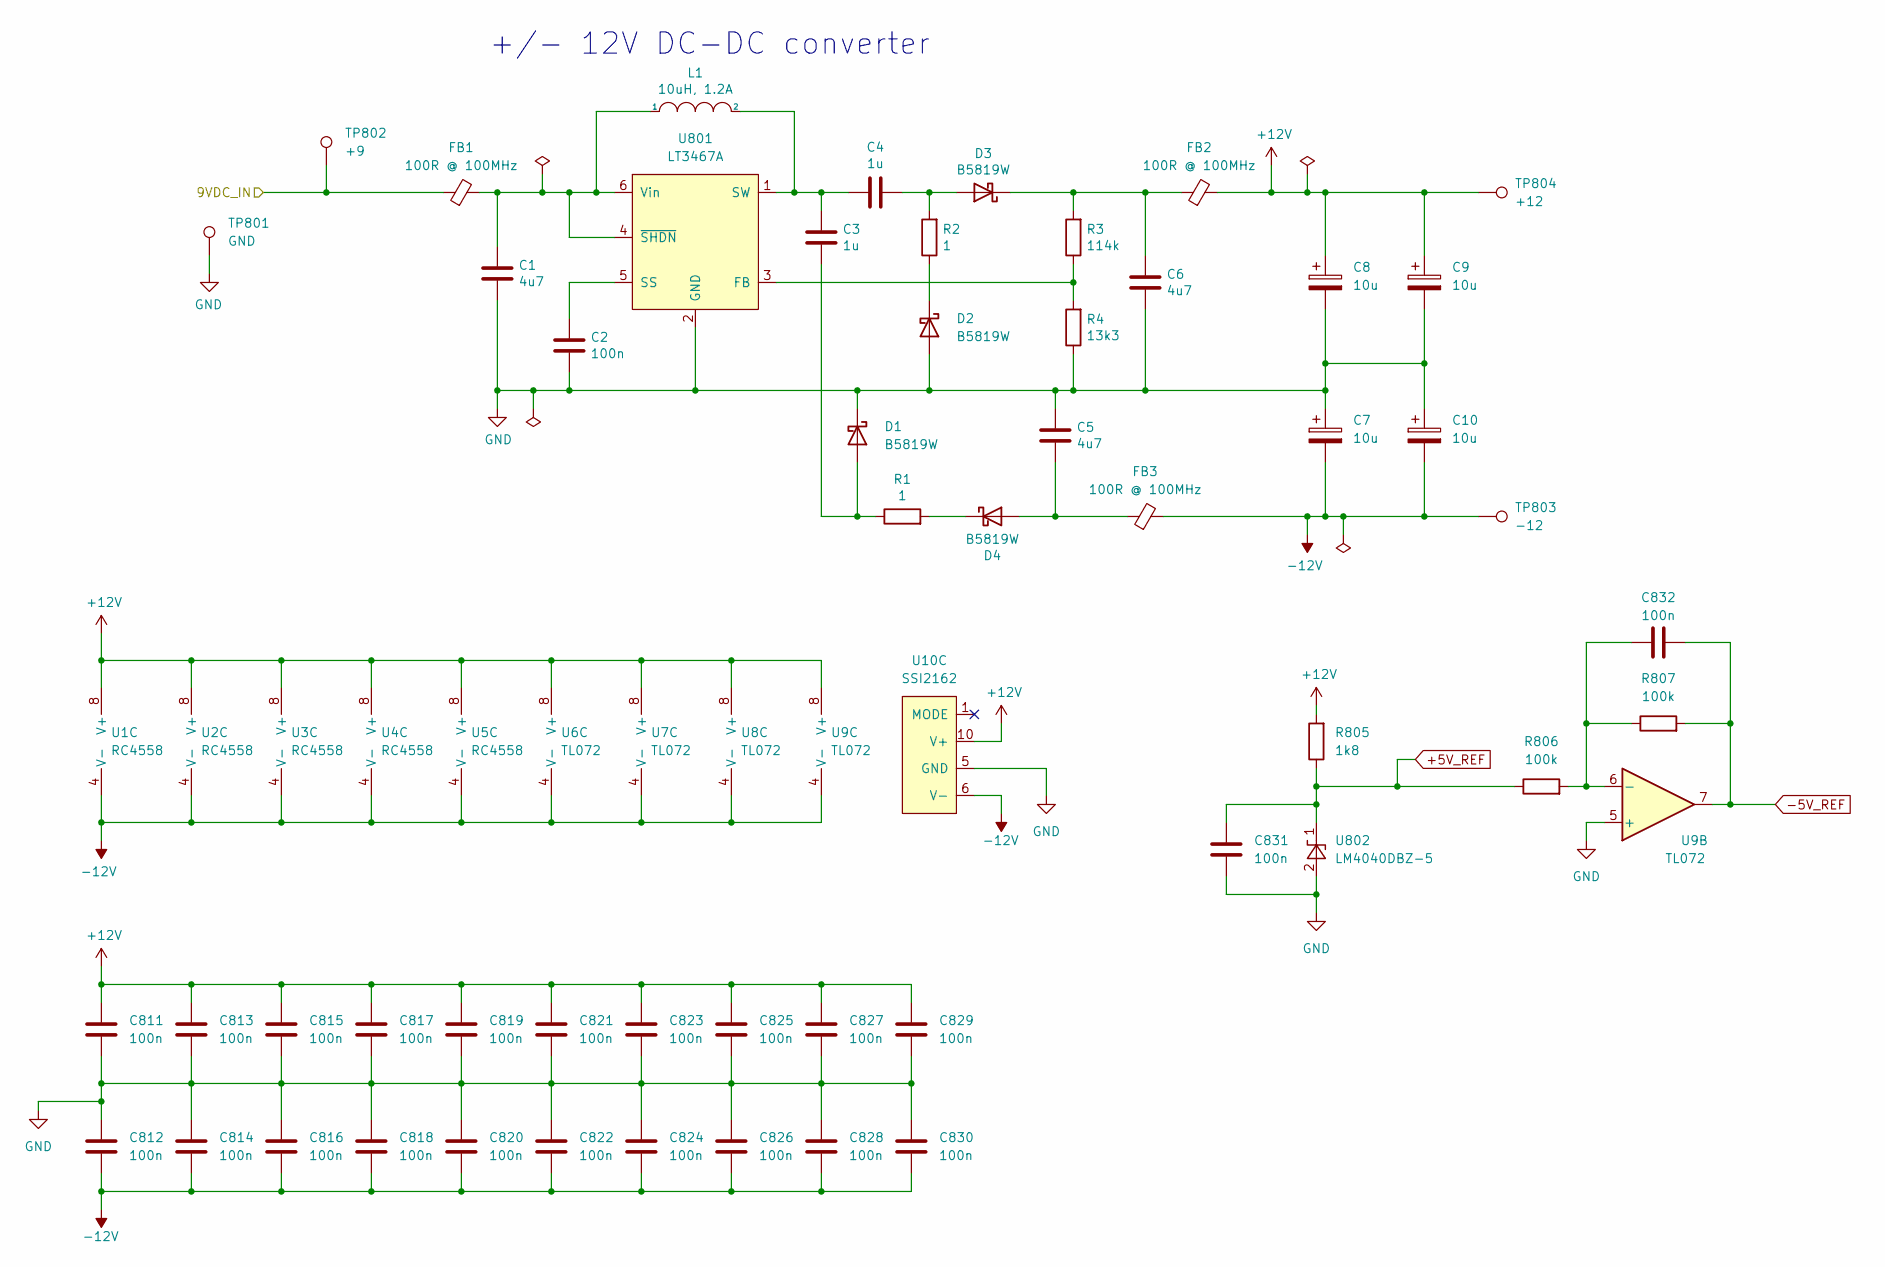
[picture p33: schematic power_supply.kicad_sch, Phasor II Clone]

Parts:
C1, C5, C6: 4u7; C_0805_2012Metric
C2, C811, C812, C813, C814, C815, C816, C817, C818, C819, C820, C821, C822, C823, C824, C825, C826, C827, C828, C829, C830, C831, C832: 100n; C_0603_1608Metric
C3, C4: 1u; C_0805_2012Metric
C7, C8, C9, C10: 10u; CP_Radial_D6.3mm_P2.50mm
D1, D2, D3, D4: B5819W; D_SOD-123
FB1, FB2, FB3: 100R @ 100MHz; L_0805_2012Metric
L1: 10uH, 1.2A; L_Taiyo-Yuden_NR-50xx
R1, R2: 1; R_0603_1608Metric
R3: 114k; R_0603_1608Metric
R4: 13k3; R_0603_1608Metric
R805: 1k8; R_0603_1608Metric
R806, R807: 100k; R_0603_1608Metric
TP801: GND; TestPoint_Bridge_Pitch7.62mm_Drill1.3mm
TP802: +9; TestPoint_Keystone_5000-5004_Miniature
TP803: -12; TestPoint_Keystone_5000-5004_Miniature
TP804: +12; TestPoint_Keystone_5000-5004_Miniature
U1, U2, U3, U4, U5: RC4558; SOIC-8_3.9x4.9mm_P1.27mm
U6, U7, U8, U9: TL072; SOIC-8_3.9x4.9mm_P1.27mm
U10: SSI2162; SSOP-10_3.9x4.9mm_P1.00mm
U801: LT3467A; TSOT-23-6
U802: LM4040DBZ-5; SOT-23

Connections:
+5V_REF: C831.1, R805.1, R806.1, U802.1 (K); also elsewhere on the board
+12V: C8.1, C9.1, C811.1, C813.1, C815.1, C817.1, C819.1, C821.1, C823.1, C825.1, C827.1, C829.1, FB2.2, R805.2, TP804.1, U1.8 (V+), U2.8 (V+), U3.8 (V+), U4.8 (V+), U5.8 (V+), U6.8 (V+), U7.8 (V+), U8.8 (V+), U9.8 (V+), U10.10 (V+); also elsewhere on the board
-5V_REF: C832.1, R807.2, U9.7; also elsewhere on the board
-12V: C7.2, C10.2, C812.2, C814.2, C816.2, C818.2, C820.2, C822.2, C824.2, C826.2, C828.2, C830.2, FB3.2, TP803.1, U1.4 (V-), U2.4 (V-), U3.4 (V-), U4.4 (V-), U5.4 (V-), U6.4 (V-), U7.4 (V-), U8.4 (V-), U9.4 (V-), U10.6 (V-)
/RAW_9VDC: FB1.1, TP802.1; also elsewhere on the board
GND: C1.2, C2.2, C5.1, C6.2, C7.1, C8.2, C9.2, C10.1, C811.2, C812.1, C813.2, C814.1, C815.2, C816.1, C817.2, C818.1, C819.2, C820.1, C821.2, C822.1, C823.2, C824.1, C825.2, C826.1, C827.2, C828.1, C829.2, C830.1, C831.2, D1.1 (K), D2.2 (A), R4.1, TP801.1, U9.5 (+), U10.5 (GND), U801.2 (GND), U802.2 (A); also elsewhere on the board
unnamed: C1.1, FB1.2, L1.1, U801.4 (~SHDN), U801.6 (Vin)
unnamed: C2.1, U801.5 (SS)
unnamed: C3.1, C4.2, L1.2, U801.1 (SW)
unnamed: C3.2, D1.2 (A), R1.1
unnamed: C4.1, D3.2 (A), R2.2
unnamed: C5.2, D4.2 (A), FB3.1
unnamed: C6.1, D3.1 (K), FB2.1, R3.2
unnamed: C832.2, R806.2, R807.1, U9.6 (-)
unnamed: D2.1 (K), R2.1
unnamed: D4.1 (K), R1.2
unnamed: R3.1, R4.2, U801.3 (FB)

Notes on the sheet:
+/- 12V DC-DC converter

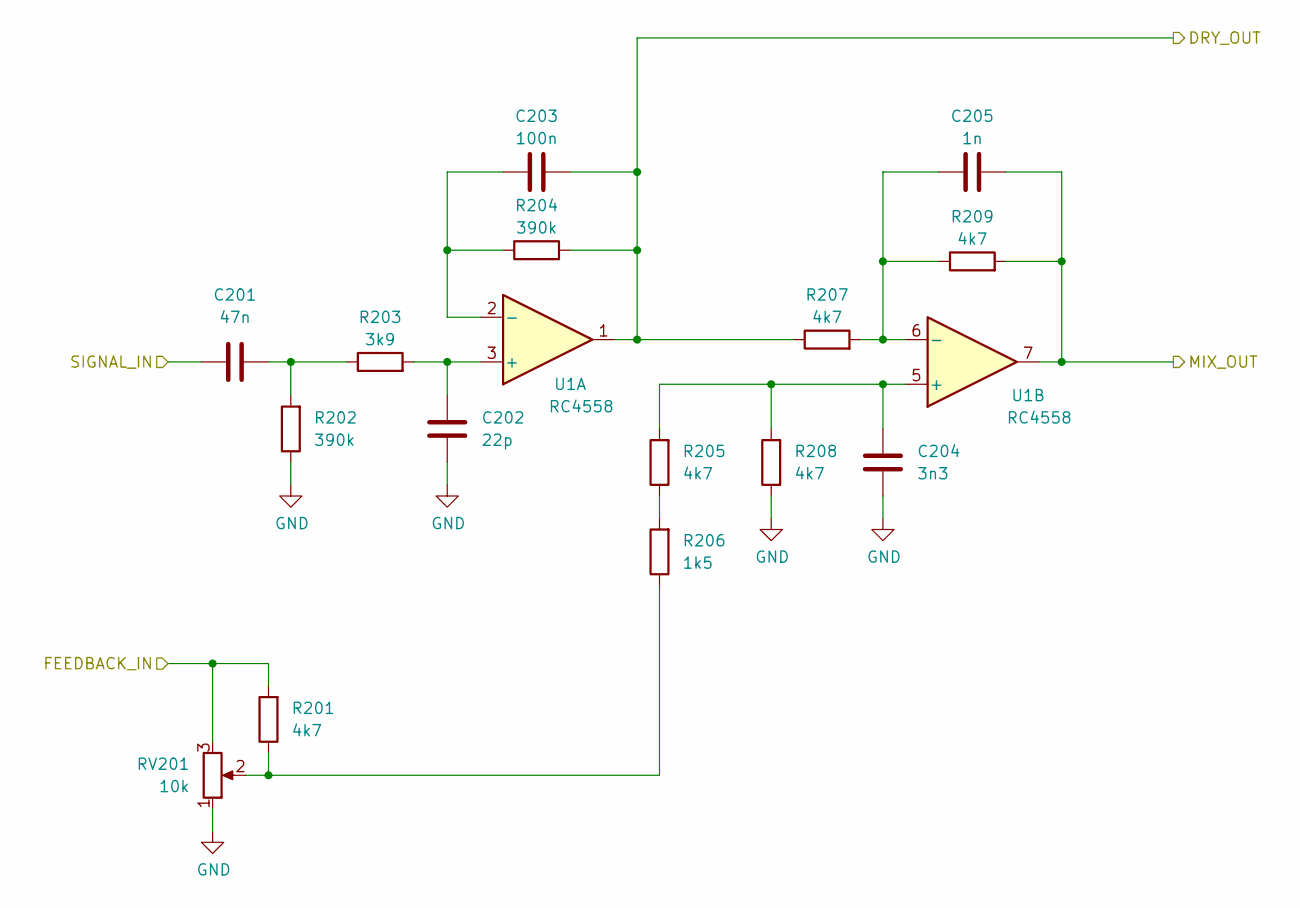
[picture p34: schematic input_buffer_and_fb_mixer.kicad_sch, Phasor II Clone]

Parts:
C201: 47n; C_Rect_L7.0mm_W2.5mm_P5.00mm
C202: 22p; C_0603_1608Metric
C203: 100n; C_0603_1608Metric
C204: 3n3; C_0603_1608Metric
C205: 1n; C_0603_1608Metric
R201, R205, R207, R208, R209: 4k7; R_0603_1608Metric
R202, R204: 390k; R_0603_1608Metric
R203: 3k9; R_0603_1608Metric
R206: 1k5; R_0603_1608Metric
RV201: 10k; Potentiometer_Alpha_RD901F-40-00D_Single_Vertical
U1: RC4558; SOIC-8_3.9x4.9mm_P1.27mm

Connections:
/allpass_stages/SIGNAL_IN: C205.2, R209.2, U1.7; also elsewhere on the board
/allpass_stages/SIGNAL_OUT: R201.2, RV201.3; also elsewhere on the board
/input_buffer_and_fb_mixer/DRY_OUT: C203.2, R204.2, R207.1, U1.1; also elsewhere on the board
/input_buffer_and_fb_mixer/SIGNAL_IN: C201.1; also elsewhere on the board
GND: C202.2, C204.2, R202.1, R208.1, RV201.1; also elsewhere on the board
unnamed: C201.2, R202.2, R203.1
unnamed: C202.1, R203.2, U1.3 (+)
unnamed: C203.1, R204.1, U1.2 (-)
unnamed: C204.1, R205.2, R208.2, U1.5 (+)
unnamed: C205.1, R207.2, R209.1, U1.6 (-)
unnamed: R201.1, R206.1, RV201.2
unnamed: R205.1, R206.2

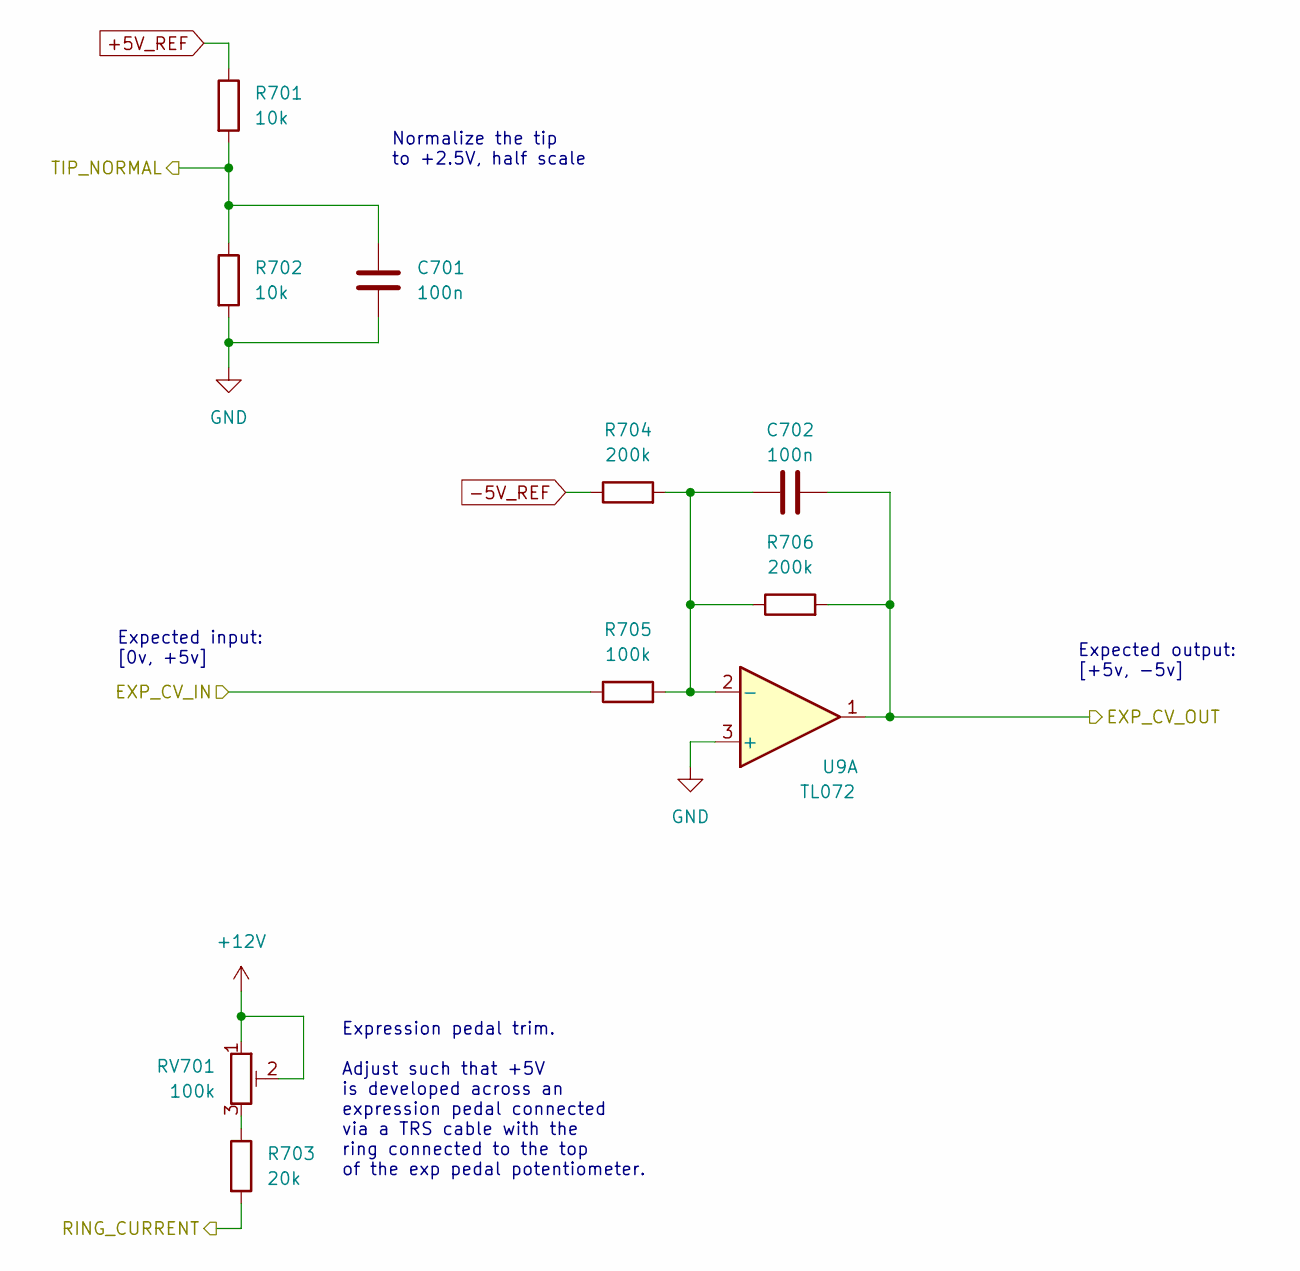
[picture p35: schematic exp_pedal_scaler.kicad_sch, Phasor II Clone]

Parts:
C701, C702: 100n; C_0603_1608Metric
R701, R702: 10k; R_0603_1608Metric
R703: 20k; R_0603_1608Metric
R704, R706: 200k; R_0603_1608Metric
R705: 100k; R_0603_1608Metric
RV701: 100k; Potentiometer_Bourns_3296W_Vertical
U9: TL072; SOIC-8_3.9x4.9mm_P1.27mm

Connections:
+5V_REF: R701.1; also elsewhere on the board
+12V: RV701.1, RV701.2; also elsewhere on the board
-5V_REF: R704.1; also elsewhere on the board
/exp_pedal_scaler/EXP_CV_IN: R705.1; also elsewhere on the board
/exp_pedal_scaler/EXP_CV_OUT: C702.1, R706.2, U9.1; also elsewhere on the board
/exp_pedal_scaler/RING_CURRENT: R703.2; also elsewhere on the board
/exp_pedal_scaler/TIP_NORMAL: C701.1, R701.2, R702.1; also elsewhere on the board
GND: C701.2, R702.2, U9.3 (+); also elsewhere on the board
unnamed: C702.2, R704.2, R705.2, R706.1, U9.2 (-)
unnamed: R703.1, RV701.3

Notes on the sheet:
Expected input: [0v, +5v]
Normalize the tip to +2.5V, half scale
Expected output: [+5v, -5v]
Expression pedal trim. Adjust such that +5V is developed across an expression pedal connected via a TRS cable with the ring connected to the top of the exp pedal potentiometer.

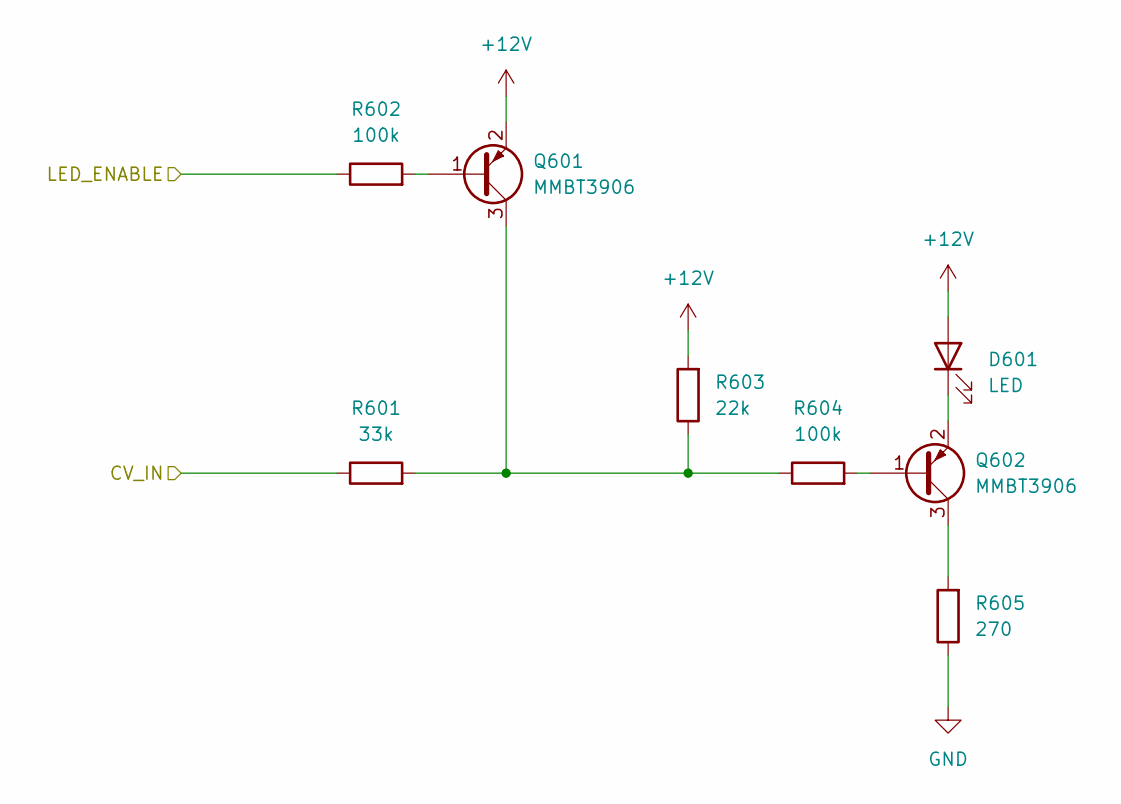
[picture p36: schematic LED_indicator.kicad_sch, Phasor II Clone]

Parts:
D601: LED; LED_D5.0mm
Q601, Q602: MMBT3906; SOT-23
R601: 33k; R_0603_1608Metric
R602, R604: 100k; R_0603_1608Metric
R603: 22k; R_0603_1608Metric
R605: 270; R_0603_1608Metric

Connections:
+12V: D601.2 (A), Q601.2 (E), R603.2; also elsewhere on the board
/CV_generator/RAW_TRI_OUT: R601.1; also elsewhere on the board
/LED_indicator/LED_ENABLE: R602.1; also elsewhere on the board
GND: R605.1; also elsewhere on the board
unnamed: D601.1 (K), Q602.2 (E)
unnamed: Q601.1 (B), R602.2
unnamed: Q601.3 (C), R601.2, R603.1, R604.1
unnamed: Q602.1 (B), R604.2
unnamed: Q602.3 (C), R605.2

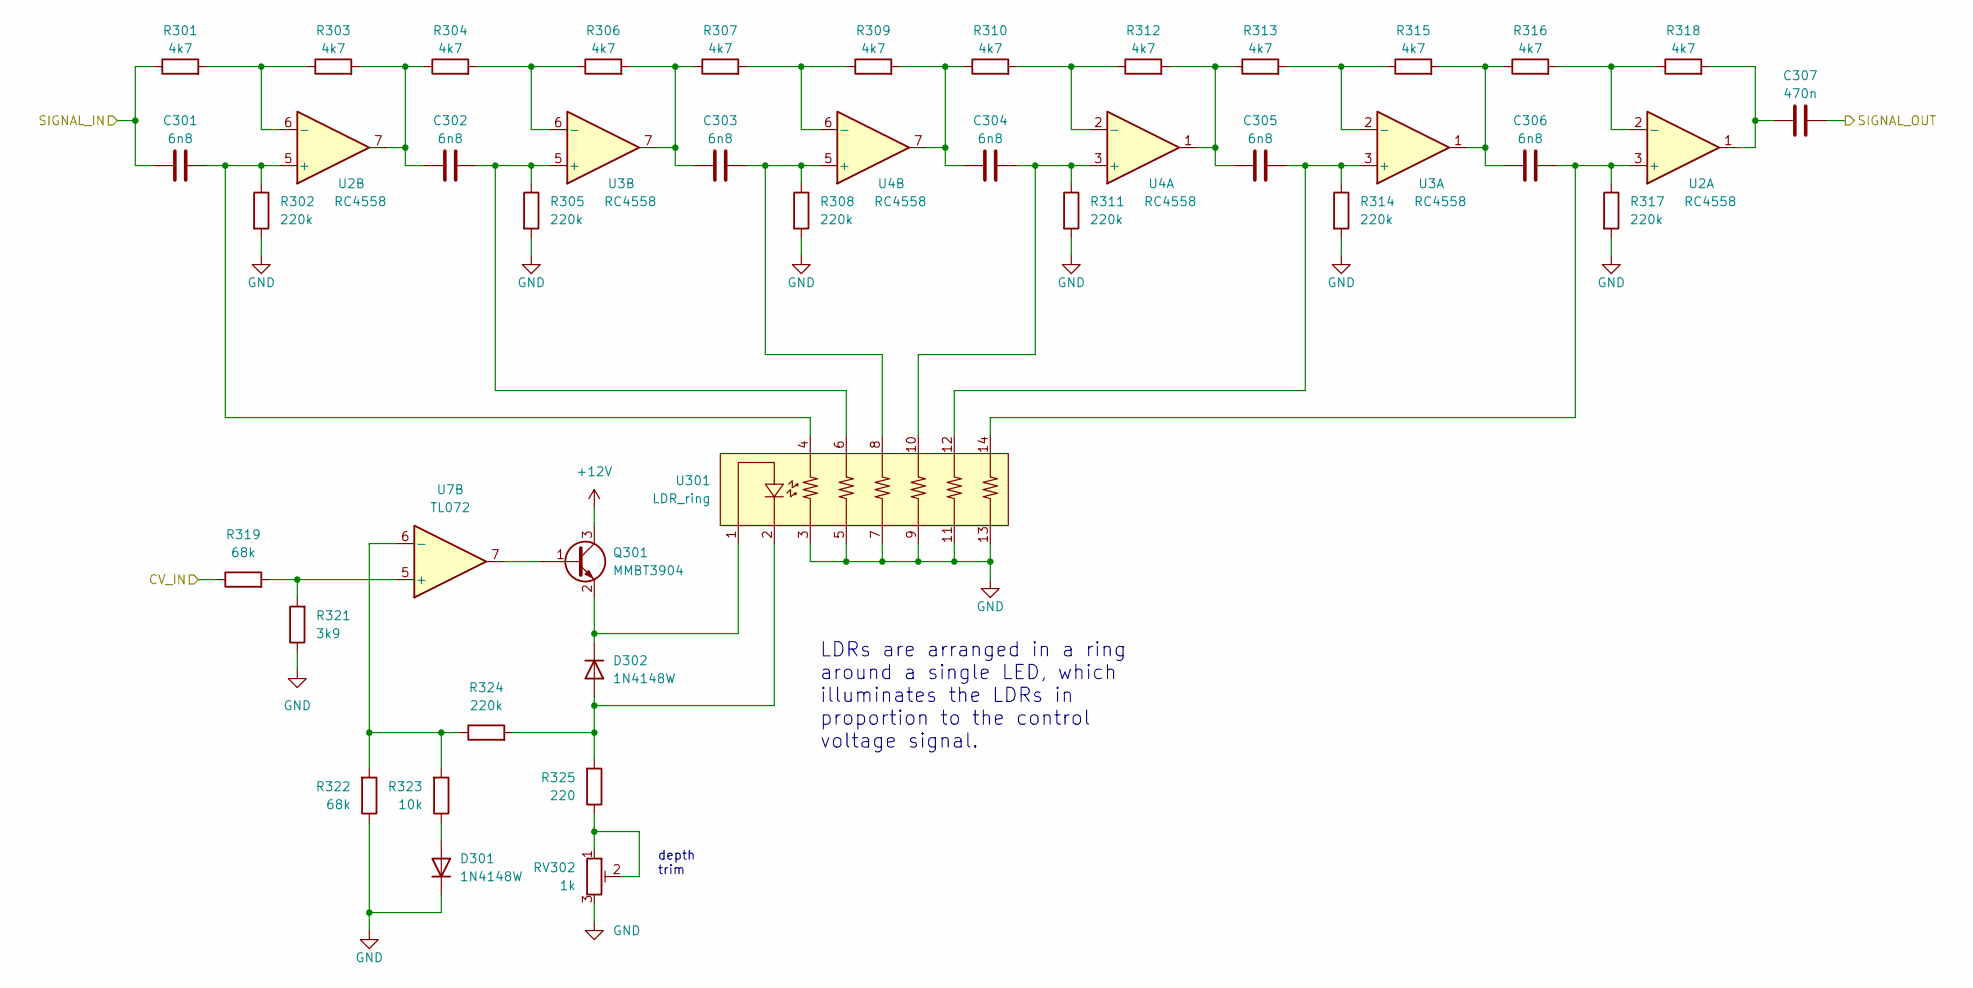
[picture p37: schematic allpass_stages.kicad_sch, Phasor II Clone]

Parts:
C301, C302, C303, C304, C305, C306: 6n8; C_0805_2012Metric
C307: 470n; C_Rect_L7.0mm_W3.5mm_P5.00mm
D301, D302: 1N4148W; D_SOD-123
Q301: MMBT3904; SOT-23
R301, R303, R304, R306, R307, R309, R310, R312, R313, R315, R316, R318: 4k7; R_0603_1608Metric
R302, R305, R308, R311, R314, R317, R324: 220k; R_0603_1608Metric
R319, R322: 68k; R_0603_1608Metric
R321: 3k9; R_0603_1608Metric
R323: 10k; R_0603_1608Metric
R325: 220; R_0603_1608Metric
RV302: 1k; Potentiometer_Bourns_3296W_Vertical
U2, U3, U4: RC4558; SOIC-8_3.9x4.9mm_P1.27mm
U7: TL072; SOIC-8_3.9x4.9mm_P1.27mm
U301: LDR_ring

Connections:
+12V: Q301.3 (C); also elsewhere on the board
/LED_CV: R319.1; also elsewhere on the board
/allpass_stages/SIGNAL_IN: C301.1, R301.1; also elsewhere on the board
/allpass_stages/SIGNAL_OUT: C307.2; also elsewhere on the board
GND: D301.1 (K), R302.2, R305.2, R308.2, R311.2, R314.2, R317.2, R321.1, R322.1, RV302.3, U301.3, U301.5, U301.7, U301.9, U301.11, U301.13; also elsewhere on the board
unnamed: C301.2, R302.1, U2.5 (+), U301.4
unnamed: C302.1, R303.2, R304.1, U2.7
unnamed: C302.2, R305.1, U3.5 (+), U301.6
unnamed: C303.1, R306.2, R307.1, U3.7
unnamed: C303.2, R308.1, U4.5 (+), U301.8
unnamed: C304.1, R309.2, R310.1, U4.7
unnamed: C304.2, R311.1, U4.3 (+), U301.10
unnamed: C305.1, R312.2, R313.1, U4.1
unnamed: C305.2, R314.1, U3.3 (+), U301.12
unnamed: C306.1, R315.2, R316.1, U3.1
unnamed: C306.2, R317.1, U2.3 (+), U301.14
unnamed: C307.1, R318.2, U2.1
unnamed: D301.2 (A), R323.1
unnamed: D302.1 (K), Q301.2 (E), U301.1
unnamed: D302.2 (A), R324.2, R325.2, U301.2
unnamed: Q301.1 (B), U7.7
unnamed: R301.2, R303.1, U2.6 (-)
unnamed: R304.2, R306.1, U3.6 (-)
unnamed: R307.2, R309.1, U4.6 (-)
unnamed: R310.2, R312.1, U4.2 (-)
unnamed: R313.2, R315.1, U3.2 (-)
unnamed: R316.2, R318.1, U2.2 (-)
unnamed: R319.2, R321.2, U7.5 (+)
unnamed: R322.2, R323.2, R324.1, U7.6 (-)
unnamed: R325.1, RV302.1, RV302.2

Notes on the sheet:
LDRs are arranged in a ring around a single LED, which illuminates the LDRs in proportion to the control voltage signal.
depth trim

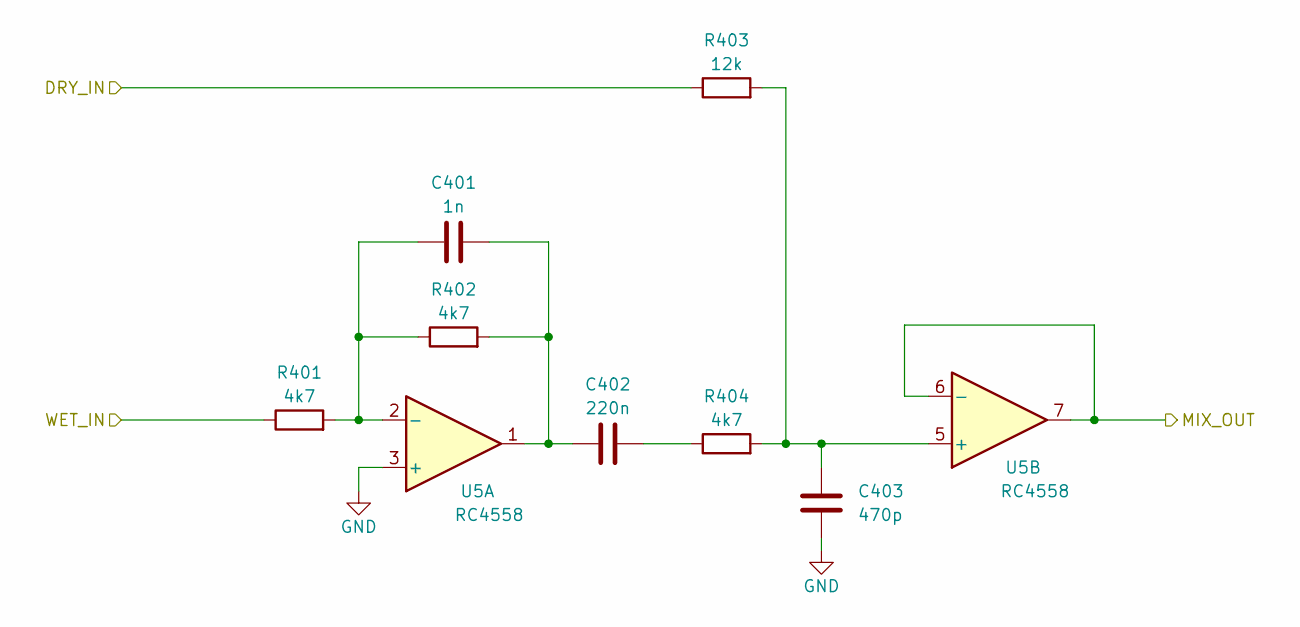
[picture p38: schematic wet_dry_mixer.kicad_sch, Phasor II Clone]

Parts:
C401: 1n; C_0603_1608Metric
C402: 220n; C_Rect_L7.0mm_W2.5mm_P5.00mm
C403: 470p; C_0603_1608Metric
R401, R402, R404: 4k7; R_0603_1608Metric
R403: 12k; R_0603_1608Metric
U5: RC4558; SOIC-8_3.9x4.9mm_P1.27mm

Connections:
/allpass_stages/SIGNAL_OUT: R401.1; also elsewhere on the board
/input_buffer_and_fb_mixer/DRY_OUT: R403.1; also elsewhere on the board
/wet_dry_mixer/MIX_OUT: U5.6 (-), U5.7; also elsewhere on the board
GND: C403.2, U5.3 (+); also elsewhere on the board
unnamed: C401.1, R401.2, R402.1, U5.2 (-)
unnamed: C401.2, C402.1, R402.2, U5.1
unnamed: C402.2, R404.1
unnamed: C403.1, R403.2, R404.2, U5.5 (+)

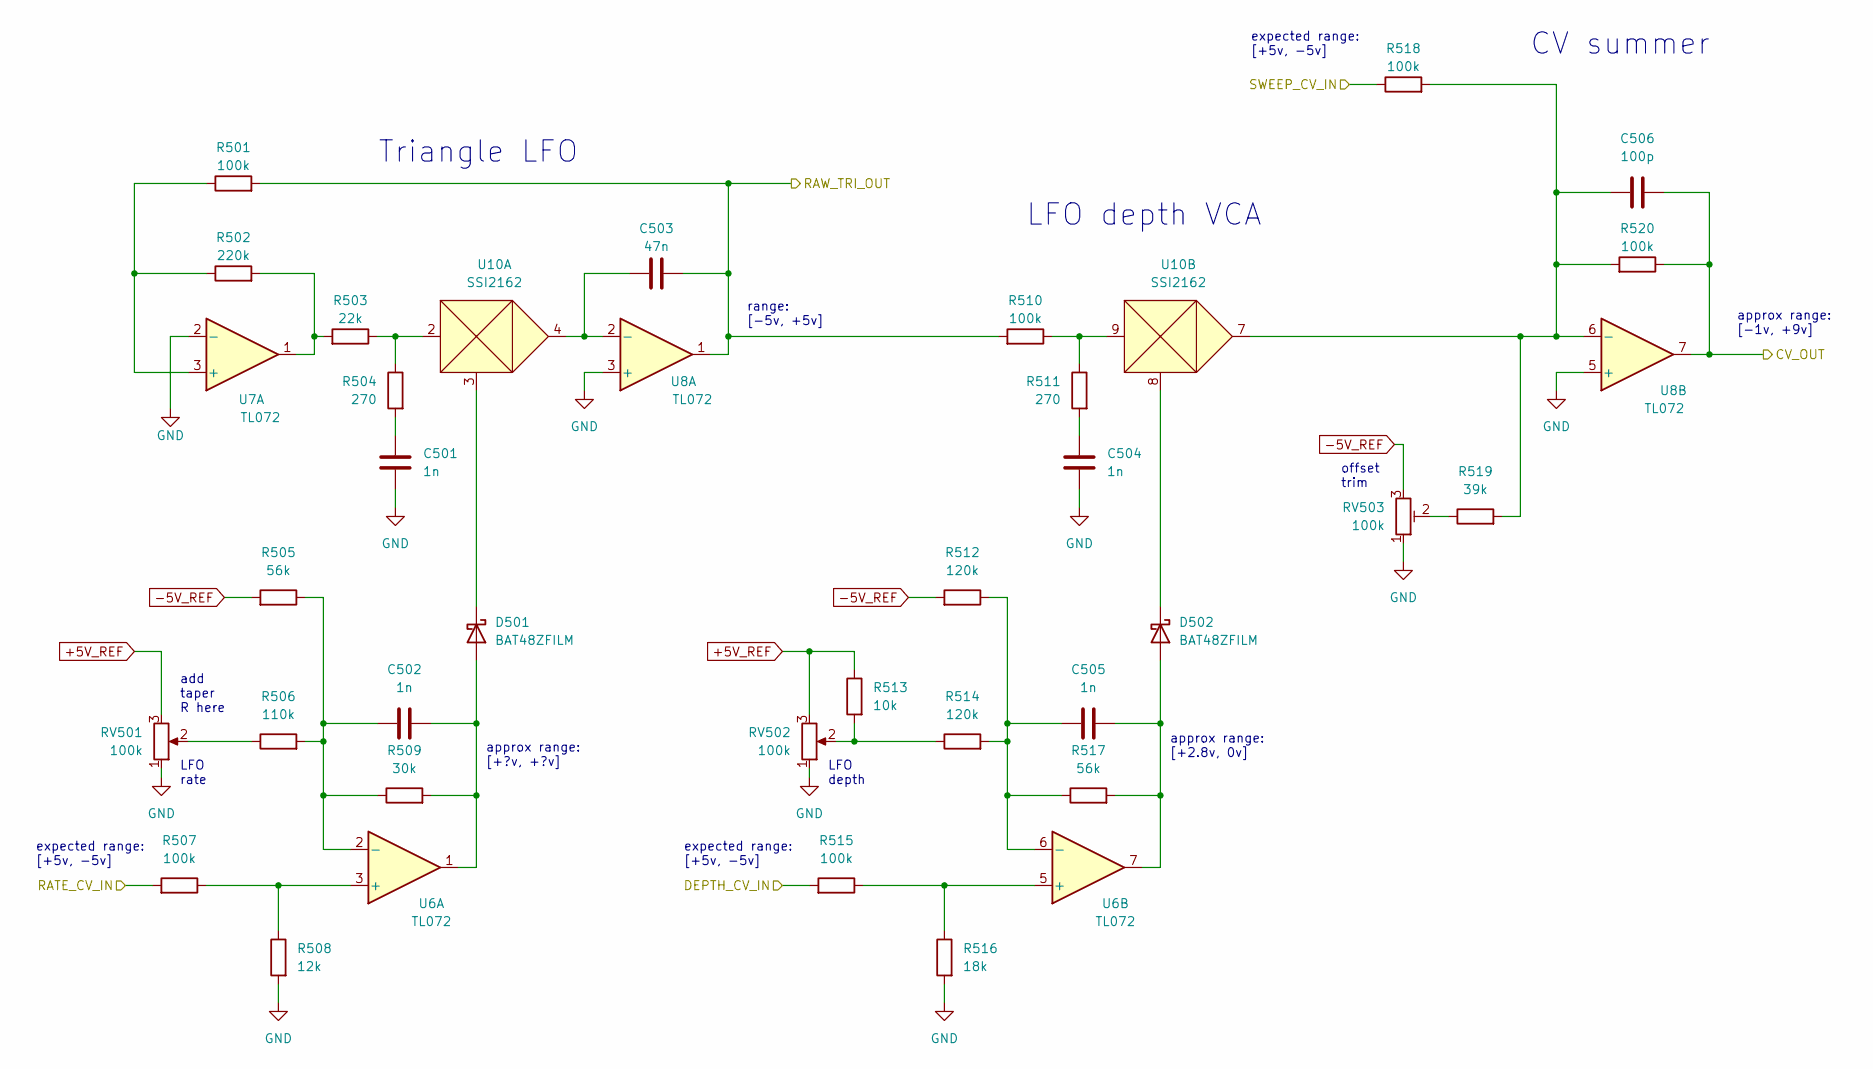
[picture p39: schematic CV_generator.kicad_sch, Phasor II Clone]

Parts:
C501, C502, C504, C505: 1n; C_0603_1608Metric
C503: 47n; C_0805_2012Metric
C506: 100p; C_0603_1608Metric
D501, D502: BAT48ZFILM; D_SOD-123
R501, R507, R510, R515, R518, R520: 100k; R_0603_1608Metric
R502: 220k; R_0603_1608Metric
R503: 22k; R_0603_1608Metric
R504, R511: 270; R_0603_1608Metric
R505, R517: 56k; R_0603_1608Metric
R506: 110k; R_0603_1608Metric
R508: 12k; R_0603_1608Metric
R509: 30k; R_0603_1608Metric
R512, R514: 120k; R_0603_1608Metric
R513: 10k; R_0603_1608Metric
R516: 18k; R_0603_1608Metric
R519: 39k; R_0603_1608Metric
RV501, RV502: 100k; Potentiometer_Alpha_RD901F-40-00D_Single_Vertical
RV503: 100k; Potentiometer_Bourns_3296W_Vertical
U6, U7, U8: TL072; SOIC-8_3.9x4.9mm_P1.27mm
U10: SSI2162; SSOP-10_3.9x4.9mm_P1.00mm

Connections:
+5V_REF: R513.1, RV501.3, RV502.3; also elsewhere on the board
-5V_REF: R505.2, R512.2, RV503.3; also elsewhere on the board
/CV_generator/DEPTH_CV_IN: R515.2; also elsewhere on the board
/CV_generator/RATE_CV_IN: R507.2; also elsewhere on the board
/CV_generator/RAW_TRI_OUT: C503.2, R501.2, R510.2, U8.1; also elsewhere on the board
/CV_generator/SWEEP_CV_IN: R518.1; also elsewhere on the board
/LED_CV: C506.1, R520.1, U8.7; also elsewhere on the board
GND: C501.2, C504.2, R508.2, R516.2, RV501.1, RV502.1, RV503.1, U7.2 (-), U8.3 (+), U8.5 (+); also elsewhere on the board
unnamed: C501.1, R504.2
unnamed: C502.1, D501.2 (A), R509.2, U6.1
unnamed: C502.2, R505.1, R506.2, R509.1, U6.2 (-)
unnamed: C503.1, U8.2 (-), U10.4
unnamed: C504.1, R511.2
unnamed: C505.1, D502.2 (A), R517.2, U6.7
unnamed: C505.2, R512.1, R514.2, R517.1, U6.6 (-)
unnamed: C506.2, R518.2, R519.2, R520.2, U8.6 (-), U10.7
unnamed: D501.1 (K), U10.3
unnamed: D502.1 (K), U10.8
unnamed: R501.1, R502.1, U7.3 (+)
unnamed: R502.2, R503.2, U7.1
unnamed: R503.1, R504.1, U10.2
unnamed: R506.1, RV501.2
unnamed: R507.1, R508.1, U6.3 (+)
unnamed: R510.1, R511.1, U10.9
unnamed: R513.2, R514.1, RV502.2
unnamed: R515.1, R516.1, U6.5 (+)
unnamed: R519.1, RV503.2

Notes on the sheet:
approx range: [+?v, +?v]
LFO depth
CV summer
approx range: [+2.8v, 0v]
LFO rate
expected range: [+5v, -5v]
add taper R here
range: [-5v, +5v]
LFO depth VCA
offset trim
approx range: [-1v, +9v]
Triangle LFO

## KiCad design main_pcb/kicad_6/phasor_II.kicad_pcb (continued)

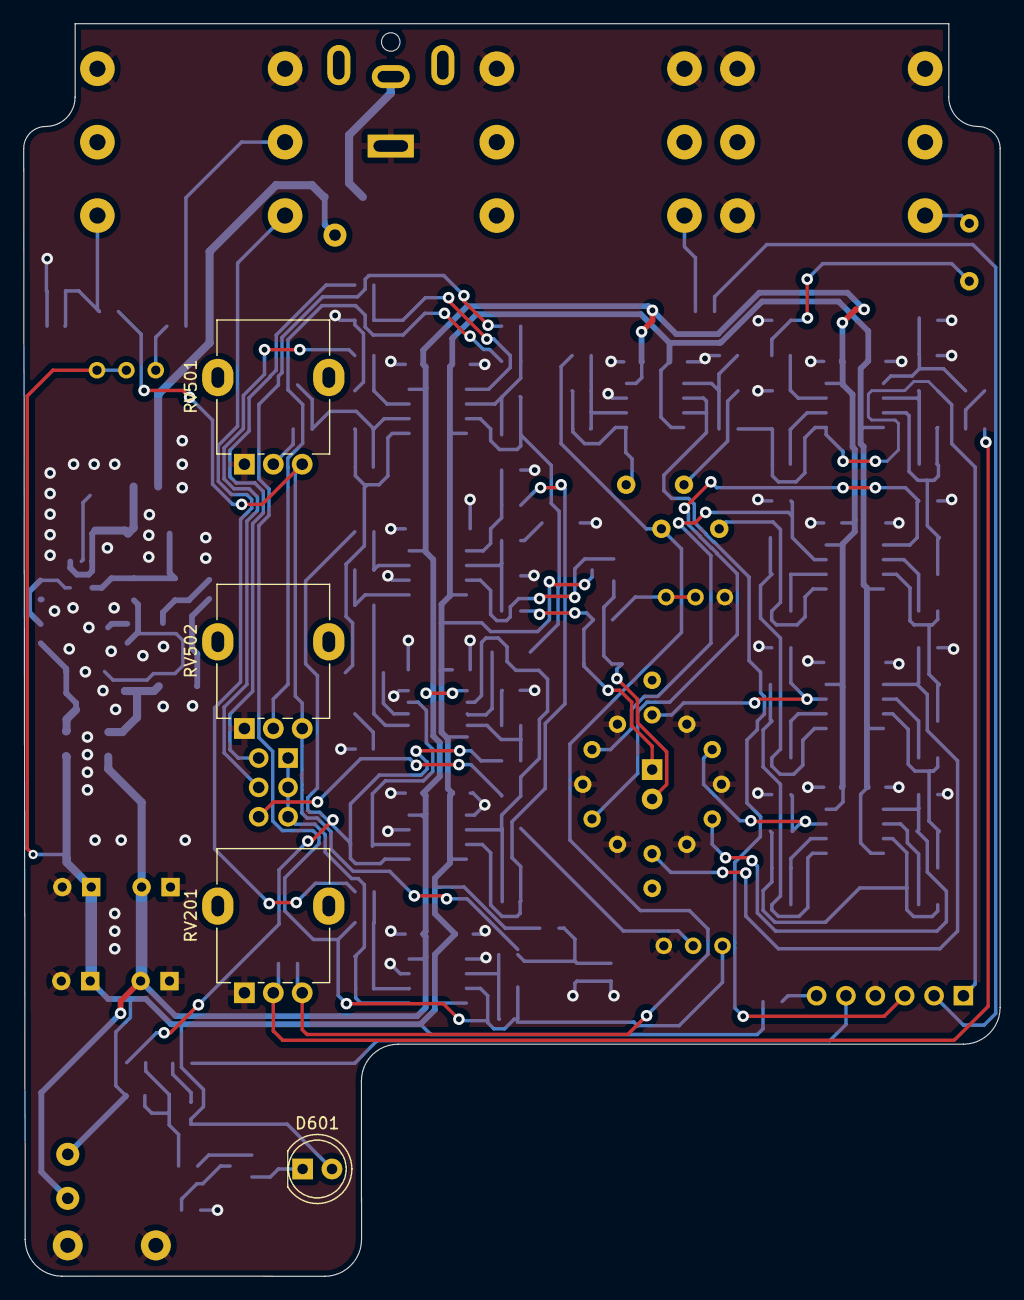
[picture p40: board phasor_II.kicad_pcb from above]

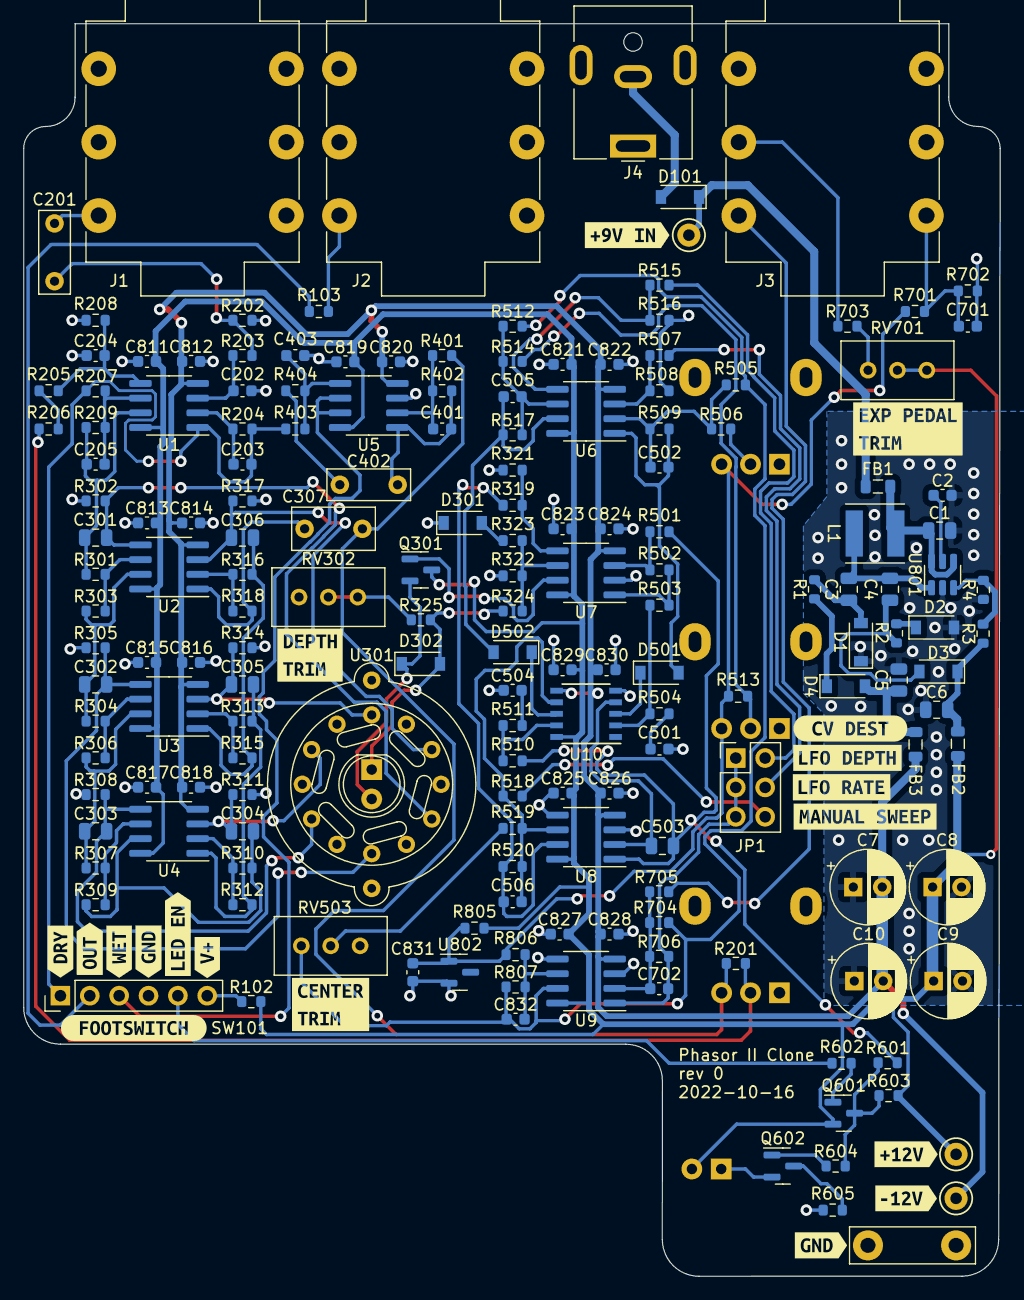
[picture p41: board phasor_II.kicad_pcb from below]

Board: 2 copper layers, 84.5 x 108.3 mm, 196 parts (192 on the bottom side), 98 nets.

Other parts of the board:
kibuzzard-634AF3B0: G***; kibuzzard-634AF3B0
kibuzzard-634AF3EB: G***; kibuzzard-634AF3EB
kibuzzard-634AF4C0: G***; kibuzzard-634AF4C0
kibuzzard-634AF4C9: G***; kibuzzard-634AF4C9
kibuzzard-634AF4D7: G***; kibuzzard-634AF4D7
kibuzzard-634AF45B: G***; kibuzzard-634AF45B
kibuzzard-634AF49E: G***; kibuzzard-634AF49E
kibuzzard-634AF397: G***; kibuzzard-634AF397
kibuzzard-634AF403: G***; kibuzzard-634AF403
kibuzzard-634AF413: G***; kibuzzard-634AF413
kibuzzard-634AF436: G***; kibuzzard-634AF436
kibuzzard-634AF448: G***; kibuzzard-634AF448
kibuzzard-634B0B87: G***; kibuzzard-634B0B87
kibuzzard-634B0BBC: G***; kibuzzard-634B0BBC
kibuzzard-634B0BDD: G***; kibuzzard-634B0BDD
kibuzzard-634B0C2B: G***; kibuzzard-634B0C2B
kibuzzard-634B3AE3: G***; kibuzzard-634B3AE3
kibuzzard-634B411E: G***; kibuzzard-634B411E

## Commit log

2023-01-30 Add notes about pcb panel thickness
2023-02-01 Fix CV range notes in schem, add note about tapering R
    [CV_generator.kicad_sch, phasor_II.kicad_sch]
2023-02-01 Add link to schematic to main readme

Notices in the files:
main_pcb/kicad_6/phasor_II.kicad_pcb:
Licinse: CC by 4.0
